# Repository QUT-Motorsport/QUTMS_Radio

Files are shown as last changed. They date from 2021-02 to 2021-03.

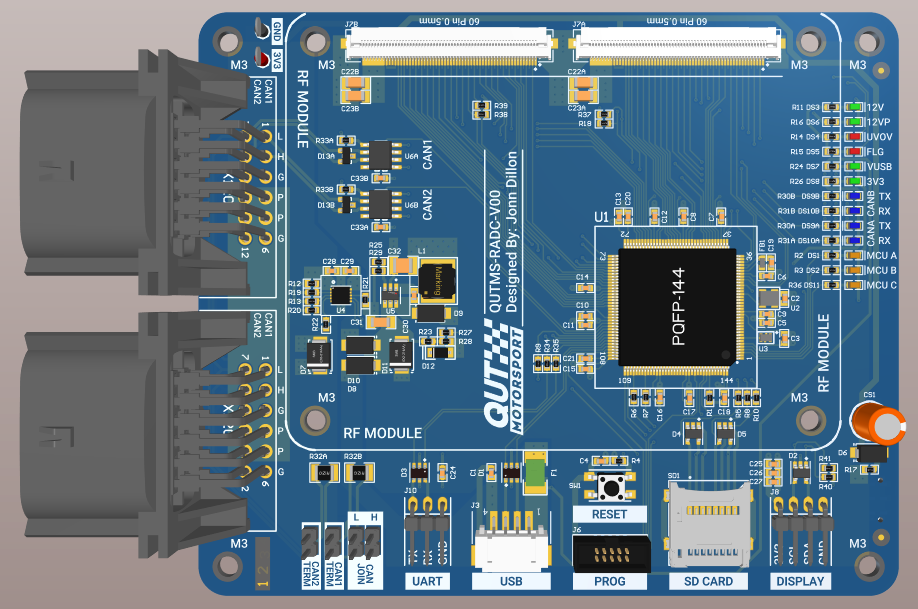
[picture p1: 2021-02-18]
RelatedImages/presentationAssembly_compute.PNG

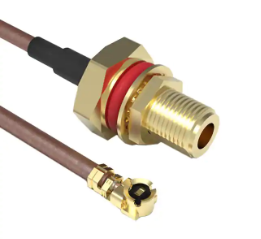
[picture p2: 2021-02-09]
RelatedImages/smaCableAssembly.PNG

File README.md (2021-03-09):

# QUTMS_Radio

## Purpose

The intent of this project is to create a robust communications link between the pits base station and one/many roving cars. Additionally the system is to provide extremely accurate RTK data.

## Project Structure

 - QUTMS-RADIO-MASTER-V00 | Overarching container for all of the projects. Open this and all other projects will open in Altium, also contains the larger mechanical assembly
 - QUTMS-RADIO-COMPUTE-V00 | The baseboard that will serve as the interface between any developed RF module and the car / base station systems
 - QUTMS-RADIO-GPS-V00 | GNSS Module
 - QUTMS-RADIO-M2M-V00 | Machine to Machine Radio module
 - QUTMS-RADIO-USB-V00 | Simple USB board to handle the issue of mounting a USB-C connector to a case
 - QUTMS-RADIO-COMPILE-V00 | Simple project to compile together all of the PCB''s into one panel
 - QUTMS-RADIO-CELL-V00 | An eventual board that will have cellular capabilities

## System configuration

For a full system there will be a total of 4 modules, 8 PCBs in total. For both the car side and pits side there will need to be a radio communications module, and a gnss module.

Ideally at the pits there will be one or two erectable tripods. One will have to hold the GNSS antenna, and needs to be high enough 

## Ordering Instructions

Only a single PCB has to be ordered for the system. This is the RAD-COMPILE pcb, a large PCB pane, 190x220mm, that contains all the PCBs needed for one side of the system (2x COMPUTE, 1x GNSS, 1x M2M).

On PCBWay's website, these are the setting required to correctly order the PCB. DO NOT DEVIATE OR RF WILL FAIL!

PCB Specification Section

- Board Type: Panel By Customer
- X-out Allowance: (Your choice, Accepting will allow some of the PCBs per panel to fail, so those failed panels will have to be accounted for in the total quantity. Not Accepting this will mean they will make a few extra PCB's (+$30) to ensure that you will have the quantity you specify of fully working panels) No/Yes 
- Different Design in Panel: 3
- Size: (Should auto fill on PCB upload) 220 x 190mm
- Quantity: 5-10 (X-Out = True -> 5, X-Out = False -> 10) (You need 2 panels min for a full system)
- Layers: 4
- Material: FR-4
- FR4-TG: TG150-160
- Thickness: 1.6mm
- Min Track/Spacing: 6/6mil
- Min Hole Size: 0.3mm
- Solder Mask: (Would prefer Green TBH due to solder mask dam thickness, but can be any colour (JUST NOT BLACK!)) Green / Purple / Blue
- Silkscreen: White
- Edge Connector: No
- Surface Finish: (Gold is an absolute must for RF) Immersion Gold (ENIG)
- Via Process: Tenting Vias
- Finished Copper: 1oz Cu
- Inner Copper: 1oz
- Extra PCB product number: (Your Choice)
- Additional Options: N/A

SMD-Stencil

- Stencil Type: Non-Framework
- Multi-level / Step Stencil: No
- Size (mm): 370x470mm (Valid Area 190 x 290mm)
- Stencil Side: Top
- Quantity: 1
- Thickness: 0.12mm
- Existing Fiducials: None (Accounted for in PCB design)
- Electropolishing: No
- Special Request: N/A

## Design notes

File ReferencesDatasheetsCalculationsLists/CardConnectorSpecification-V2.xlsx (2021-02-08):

PINOUT
ID | PWR | SIG | SIG DESC | STATE
1 | GND
2 |  | USART | TX | HIGH SPEED
3 | GND
4 |  | USART | RX | HIGH SPEED
5 | GND
6 |  | USART | CTS | HIGH SPEED
7 | GND
8 |  | USART | RTS | HIGH SPEED
9 | GND
10 |  | UART | TX | HIGH SPEED
11 | GND
12 |  | UART | RX | HIGH SPEED
13 | GND
14 |  | SPI | CLK | HIGH SPEED
15 | GND
16 |  | SPI | MISO | HIGH SPEED
17 | GND
18 |  | SPI | MOSI | HIGH SPEED
19 | GND
20 |  | SPI | CS | HIGH SPEED
21 | GND
22 |  | I2C | CLK | HIGH SPEED
23 | GND
24 |  | I2C | SDA | HIGH SPEED
25 | GND
26 |  | GENERIC |  | UNKNOWN
27 | GND
28 |  | GENERIC |  | UNKNOWN
29 | GND
30 |  | GENERIC |  | UNKNOWN
31 | GND
32 |  | GENERIC |  | UNKNOWN
33 | GND
34 |  | GENERIC |  | UNKNOWN
35 | GND
36 |  | GENERIC |  | UNKNOWN
37 | GND
38 |  | GENERIC |  | UNKNOWN
39 | GND
40 |  | GENERIC |  | UNKNOWN
41 | GND
42 |  | GENERIC |  | UNKNOWN
43 | GND
44 |  | GENERIC |  | UNKNOWN
45 | GND
46 |  | MODULE DET |  | STATIC
47 |  | MODULE DET |  | STATIC
48 | GND
49 | RTC BAT |  |  | RTC
50 | RTC BAT |  |  | RTC
51 | GND
52 | 3V3 |  |  | PWR
53 | 3V3 |  |  | PWR
54 | 3V3 |  |  | PWR
55 | 3V3 |  |  | PWR
56 | 3V3 |  |  | PWR
57 | 3V3 |  |  | PWR
58 | 3V3 |  |  | PWR
59 | 3V3 |  |  | PWR
60 | 3V3 |  |  | PWR

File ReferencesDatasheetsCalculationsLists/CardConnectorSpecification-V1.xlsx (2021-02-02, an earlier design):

RADC / RADM / RADG Card Interconnect specification
PCI-E Right Angle Connector: PCIE-036-02-F-D-RA
Bottom Row |  | Top Row |  | Each Card Requires
Pin | Intent | Pin | Intent
 |  |  |  | 1 SPI | 4
A1 | GND | B1 | 3V3 | 1 Syn USART | 5
A2 | SPI MISO | B2 | RTC BAT | 1 Asyn UART | 2
A3 | SPI MOSI | B3 | I2C SDA | 1 I2C | 2
A4 | SPI CLK | B4 | I2C SCL | 8 Extra | 8
A5 | SPI CS | B5 | 3V3 | Module Det | 1 | ADC Voltage
A6 | GND | B6 | USART1 TX
A7 | UART2 TX | B7 | USART1 RX
A8 | UART2 RX | B8 | USART1 RTS
A9 | Module Detect | B9 | USART1 CTS
A10 | Module Detect | B10 | USART1 DTR
A11 | GND | B11 | 3V3 |  |  |  | Module 1 | 26
 |  |  |  |  |  |  | Module 2 | 26
A12 | GND | B12 | 3V3 |  |  |  | SD | 7
A13 | Connected Pin | B13 | Connected Pin |  |  |  | CAN | 3
A14 | Connected Pin | B14 | Connected Pin |  |  |  | PWR | 3
A15 | Connected Pin | B15 | Connected Pin |  |  |  | I2C | 2
A16 | Connected Pin | B16 | Connected Pin
A17 | Connected Pin | B17 | Connected Pin
A18 | GND | B18 | 3V3

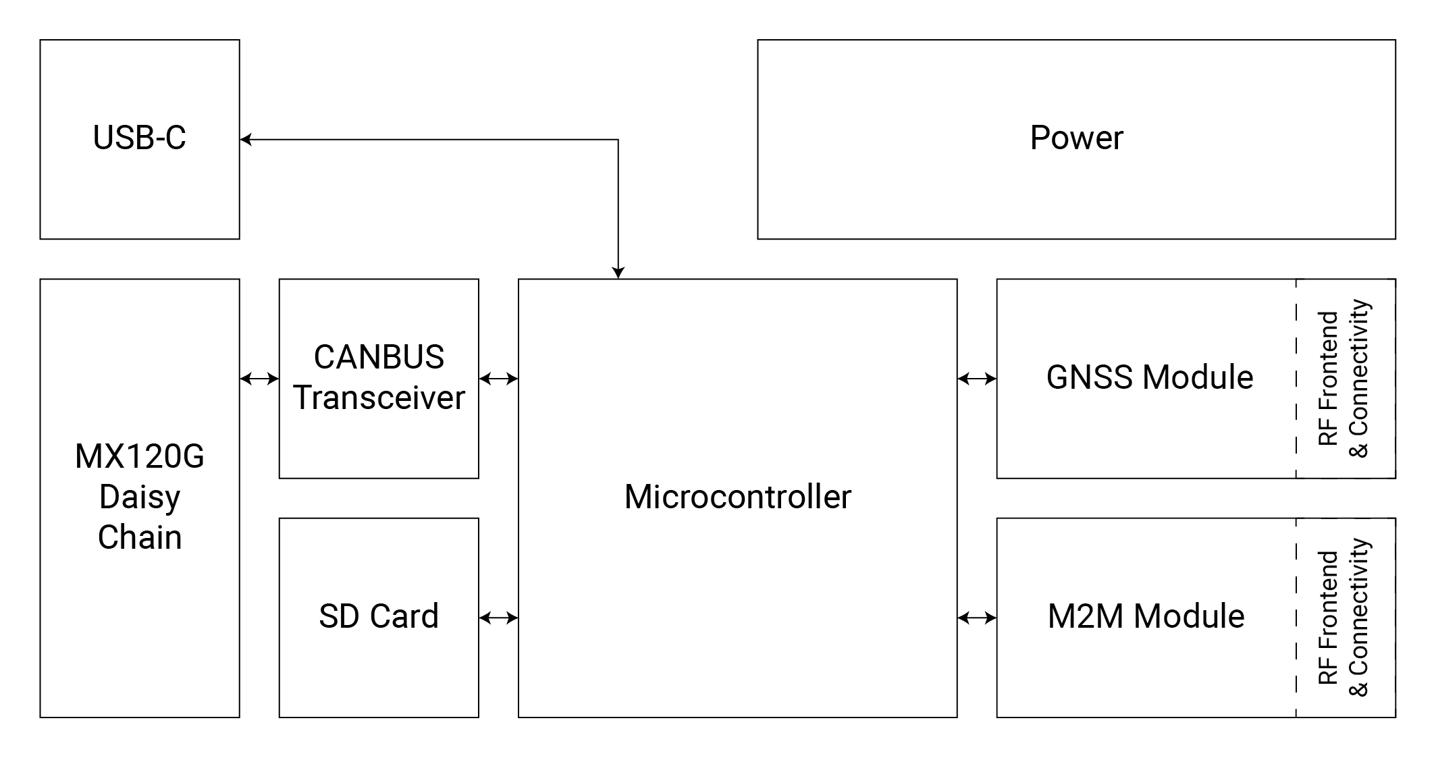
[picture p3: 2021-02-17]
RelatedImages/requirementsArchitectureDiagram-01.png

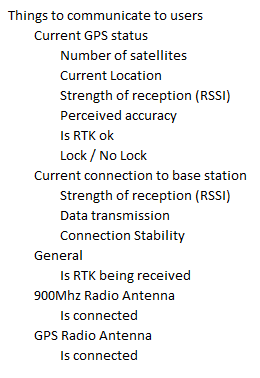
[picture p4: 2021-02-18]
RelatedImages/oledDisplayRequirements.PNG

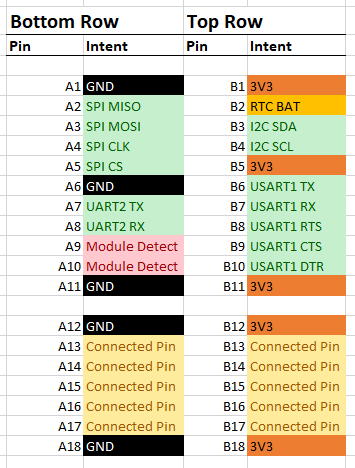
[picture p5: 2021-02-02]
RelatedImages/cardConnectorSpecification-V1.PNG

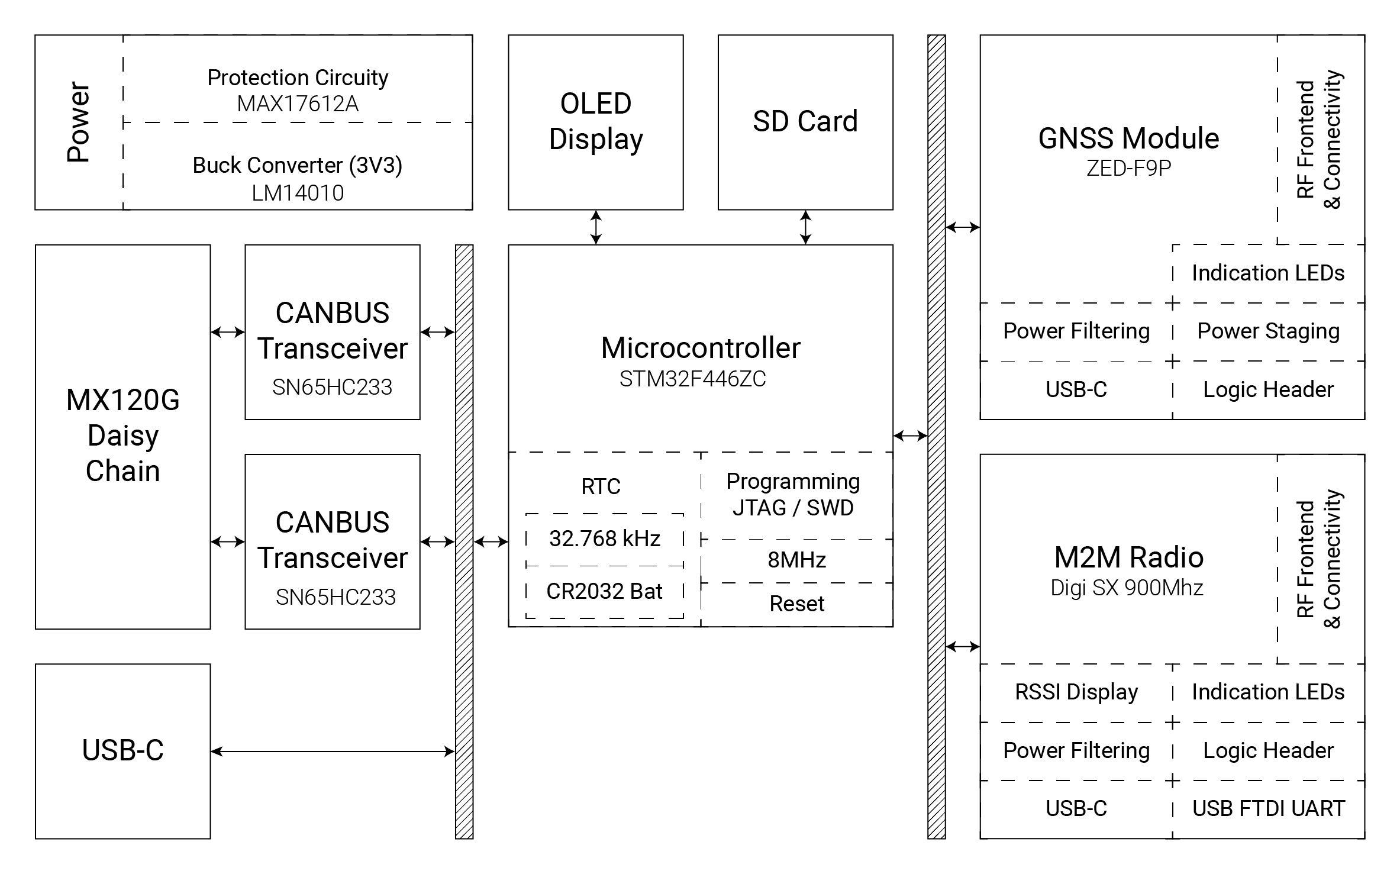
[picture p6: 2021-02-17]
RelatedImages/ultimateArchitectureDiagram-01.png

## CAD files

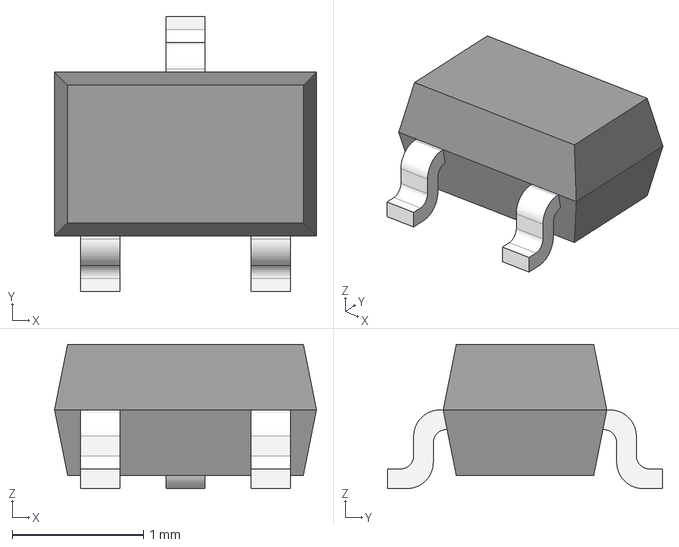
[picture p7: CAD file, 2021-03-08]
3DModels/SC70-3.step
2.00 x 2.10 x 1.10 mm

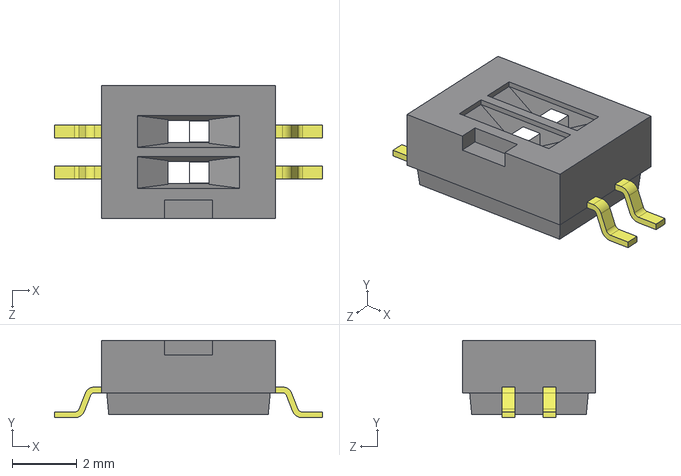
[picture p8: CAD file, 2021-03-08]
3DModels/CUI_DEVICES_DS05-127-2-02BK-SMT-TR.step
8.30 x 2.40 x 4.11 mm

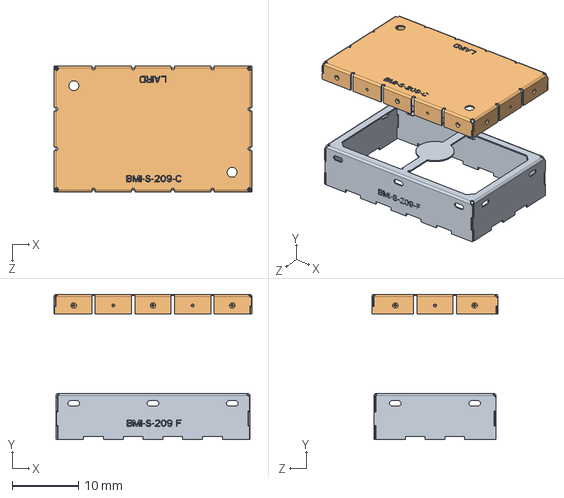
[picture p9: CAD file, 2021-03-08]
3DModels/Laird-BMI-S-209 Frame and Cover.STEP
30.0 x 22.0 x 19.1 mm
Laird-BMI-S-209-F and BMI-S-209-C_BMI-S-209-F
Laird-BMI-S-209-F and BMI-S-209-C_BMI-S-209-C

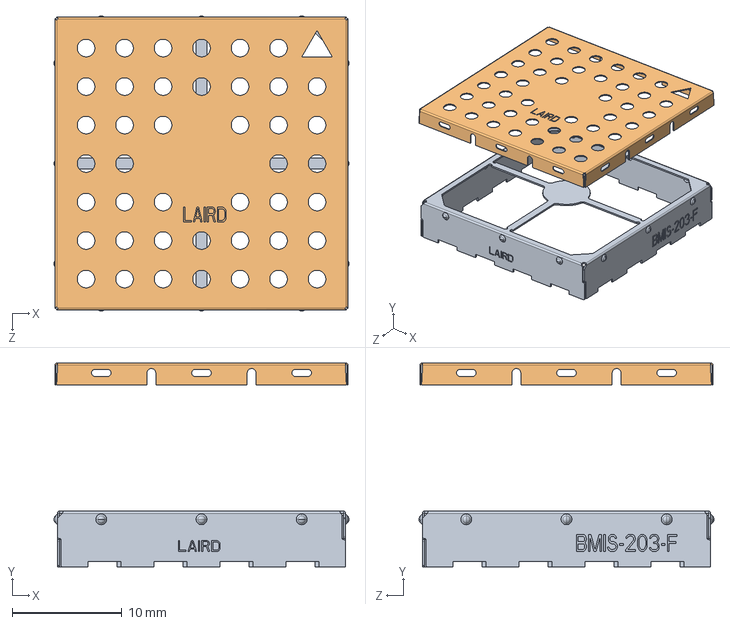
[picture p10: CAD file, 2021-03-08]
3DModels/Laird-BMI-S-203 Frame and Cover.STEP
26.8 x 18.5 x 26.8 mm
Laird-BMI-S-203-F and BMI-S-203-C_BMI-S-203-F
Laird-BMI-S-203-F and BMI-S-203-C_BMI-S-203-C

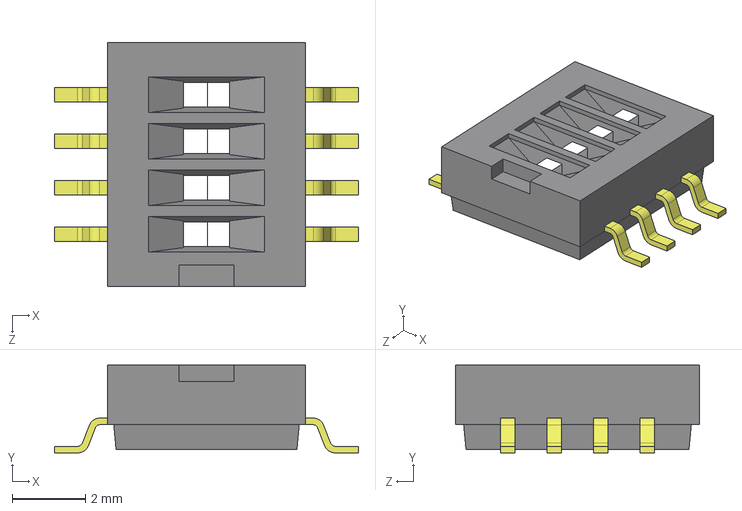
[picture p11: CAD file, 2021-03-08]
3DModels/CUI_DEVICES_DS05-127-2-04BK-SMT-TR.step
8.30 x 2.40 x 6.65 mm

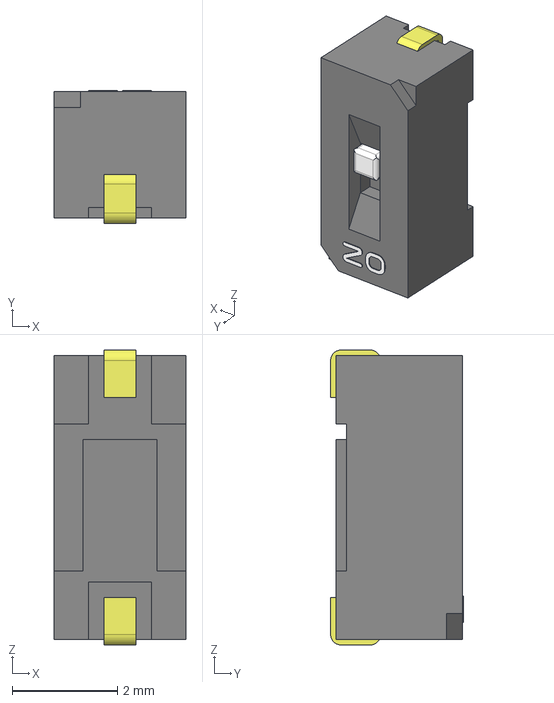
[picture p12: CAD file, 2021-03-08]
3DModels/CHS-01TA.stp
2.50 x 2.52 x 5.60 mm
_CHS-01-J-body
_CHS-slider

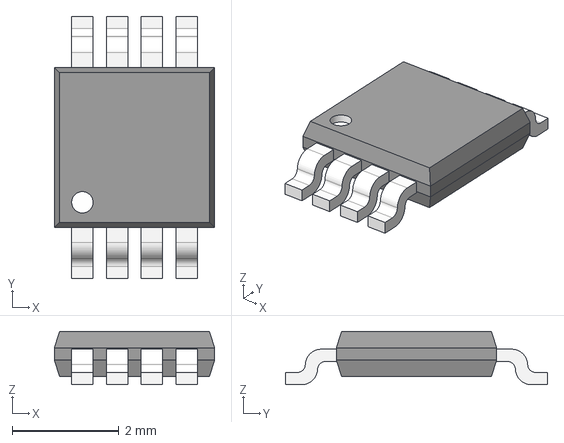
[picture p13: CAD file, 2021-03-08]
3DModels/MSOP-08 0.65p 3mm.step
3.00 x 4.90 x 1.00 mm

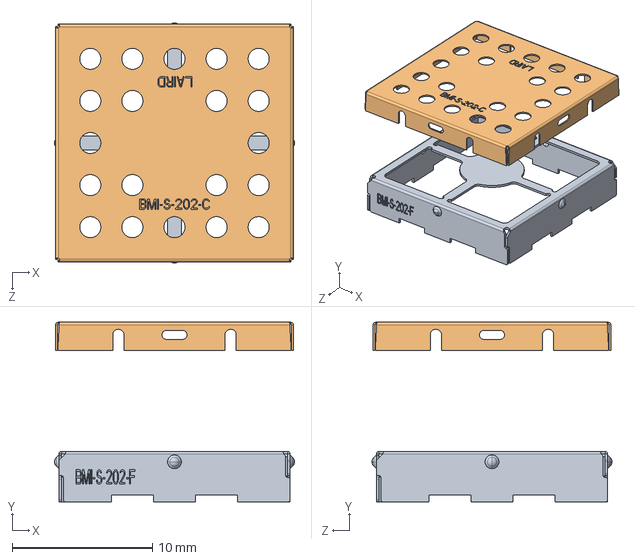
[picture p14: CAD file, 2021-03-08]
3DModels/Laird-BMI-S-202 Frame and Cover.STEP
17.1 x 12.8 x 17.1 mm
Laird-BMI-S-202-F and BMI-S-202-C_BMI-S-202-F
Laird-BMI-S-202-F and BMI-S-202-C_BMI-S-202-C

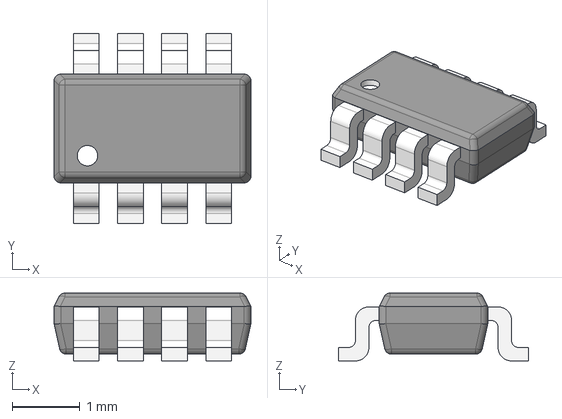
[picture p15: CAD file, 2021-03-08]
3DModels/TSOT-8.step
2.90 x 2.80 x 1.00 mm

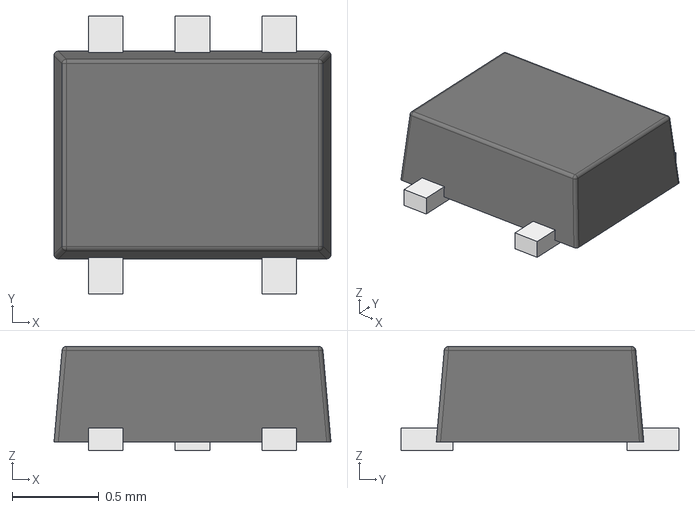
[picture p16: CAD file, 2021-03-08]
3DModels/SOT-23-5-TI-DRL v2.step
1.60 x 1.60 x 0.6 mm

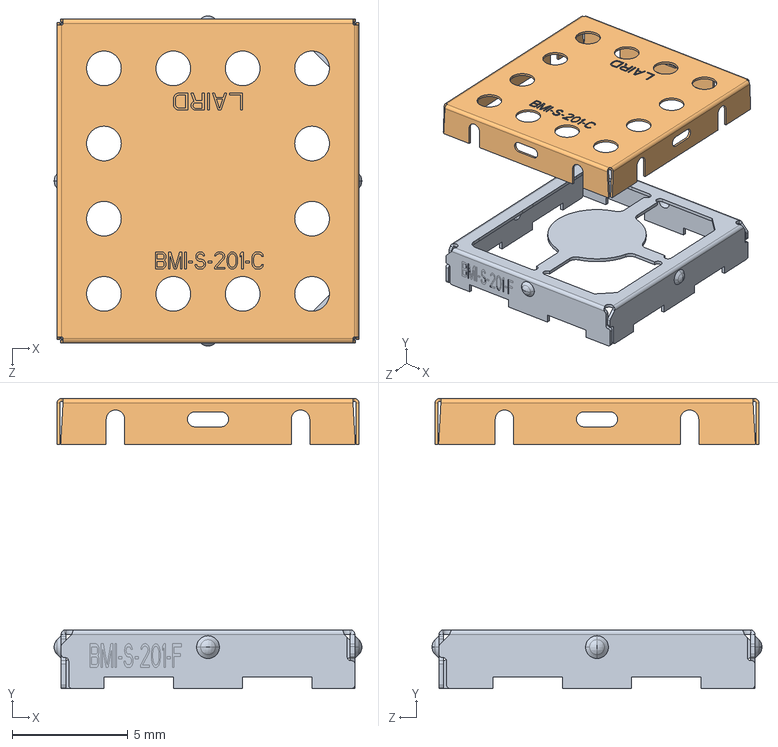
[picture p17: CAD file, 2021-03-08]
3DModels/Laird-BMI-S-201 Frame and Cover.STEP
13.3 x 12.5 x 14.3 mm
Laird-BMI-S-201-F and BMI-S-201-C_BMI-S-201-F
Laird-BMI-S-201-F and BMI-S-201-C_BMI-S-201-C

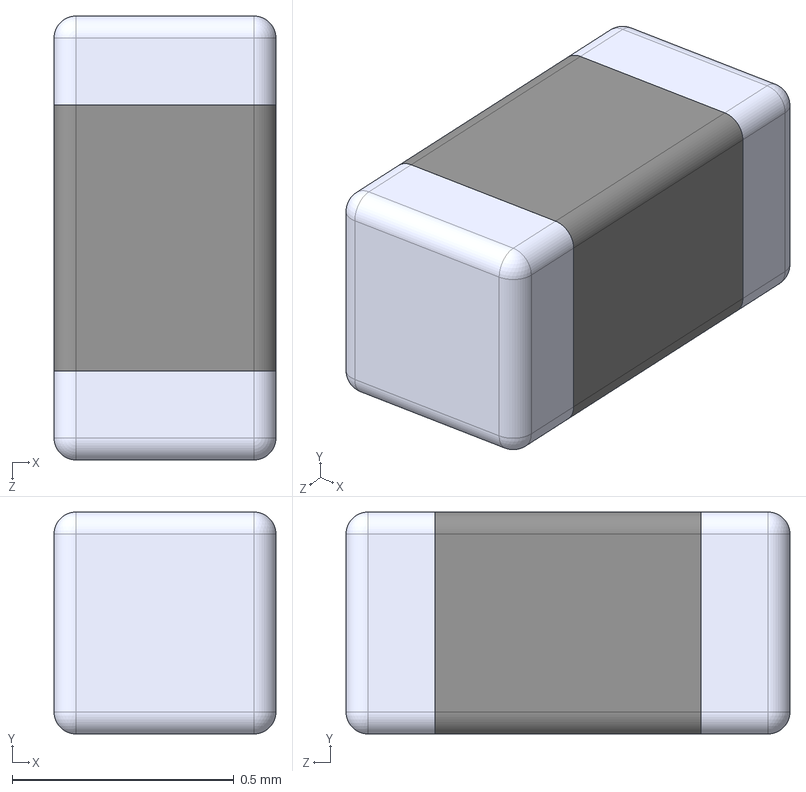
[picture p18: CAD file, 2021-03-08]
3DModels/ferrite_bead_0402.STEP
0.5 x 0.5 x 1.00 mm

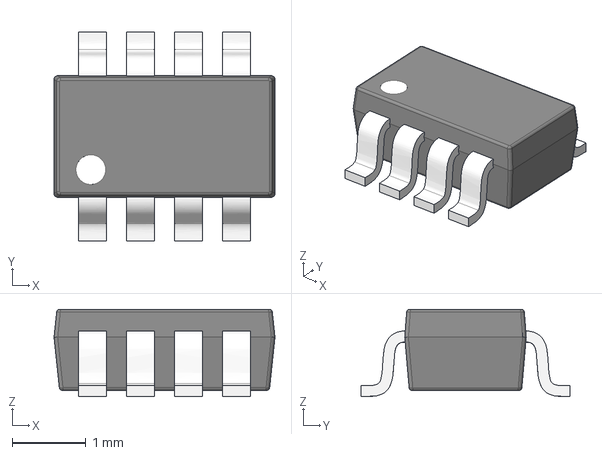
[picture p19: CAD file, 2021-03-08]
3DModels/SOT23-8.stp
3.00 x 2.84 x 1.18 mm

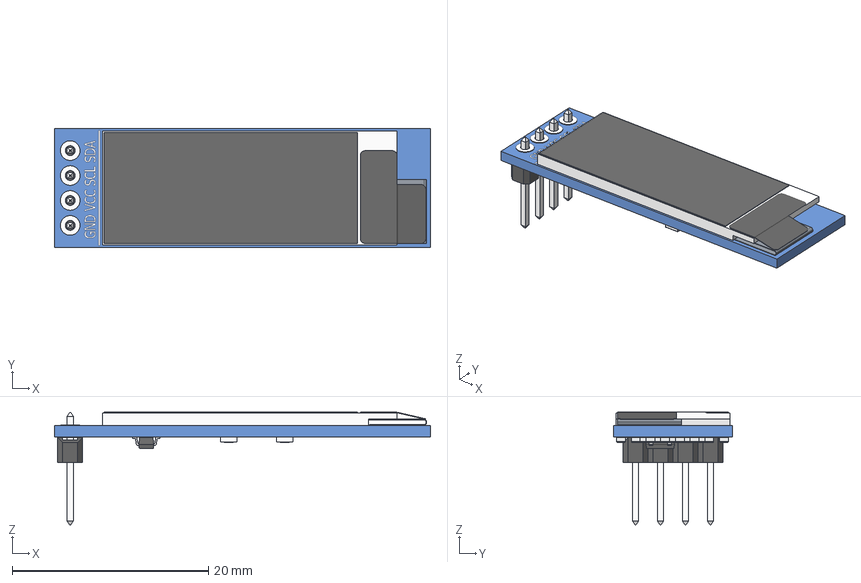
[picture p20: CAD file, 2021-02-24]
3DModels/OLED_0.91_128x32.stp
38.3 x 12.1 x 11.5 mm
OLED_0.91_128x32
Pin Header 4 x 1 TH 2.54mm Pitch
RESC-0603 x 13
2SD0601A

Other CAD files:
3DModels/OLEDDisplay1-3inch.stp
3DModels/1812_RES.stp
3DModels/TSSOP-14 0.65p 4.4mm.step
3DModels/pqfpfp144_p0-5_l20_w20.stp
3DModels/022288030.stp
3DModels/022288040.stp
3DModels/0ZCJ0005FF2E.step
3DModels/20-Pin Shrouded Header (IDC) Straight.stp
3DModels/30326-6002.stp
3DModels/61300411121_Download_STP_61300411121_rev1.stp
3DModels/68021-x08.igs
3DModels/74279270_Download_STP_WE-CBF-0402_rev1.stp
3DModels/Aluminum_electrolytic_capacitor_radial_D6.3_H9_PinD0.5_Pitch2.5_nominal_orange.step
3DModels/CUI_PJ-102A.STEP
3DModels/JS202011JAQN.stp
3DModels/JS202011JCQN.stp
3DModels/JST - PH - SMD (R) - 4Pin - 2.00mm.stp
3DModels/JST - PH - Thru (V) - 4Pin - 2.00mm.stp
3DModels/LQFP100_14X14X1.6_P0.5_ST.step
3DModels/M3x1.8mm Hex Nut.step
3DModels/M3x8.STEP
3DModels/NFE31PT101C1E9L.STEP
3DModels/PCIE-036-02-F-D-RA.stp
3DModels/SC-74-3.stp
3DModels/SC-74-4.stp
3DModels/SC-74-5.stp
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

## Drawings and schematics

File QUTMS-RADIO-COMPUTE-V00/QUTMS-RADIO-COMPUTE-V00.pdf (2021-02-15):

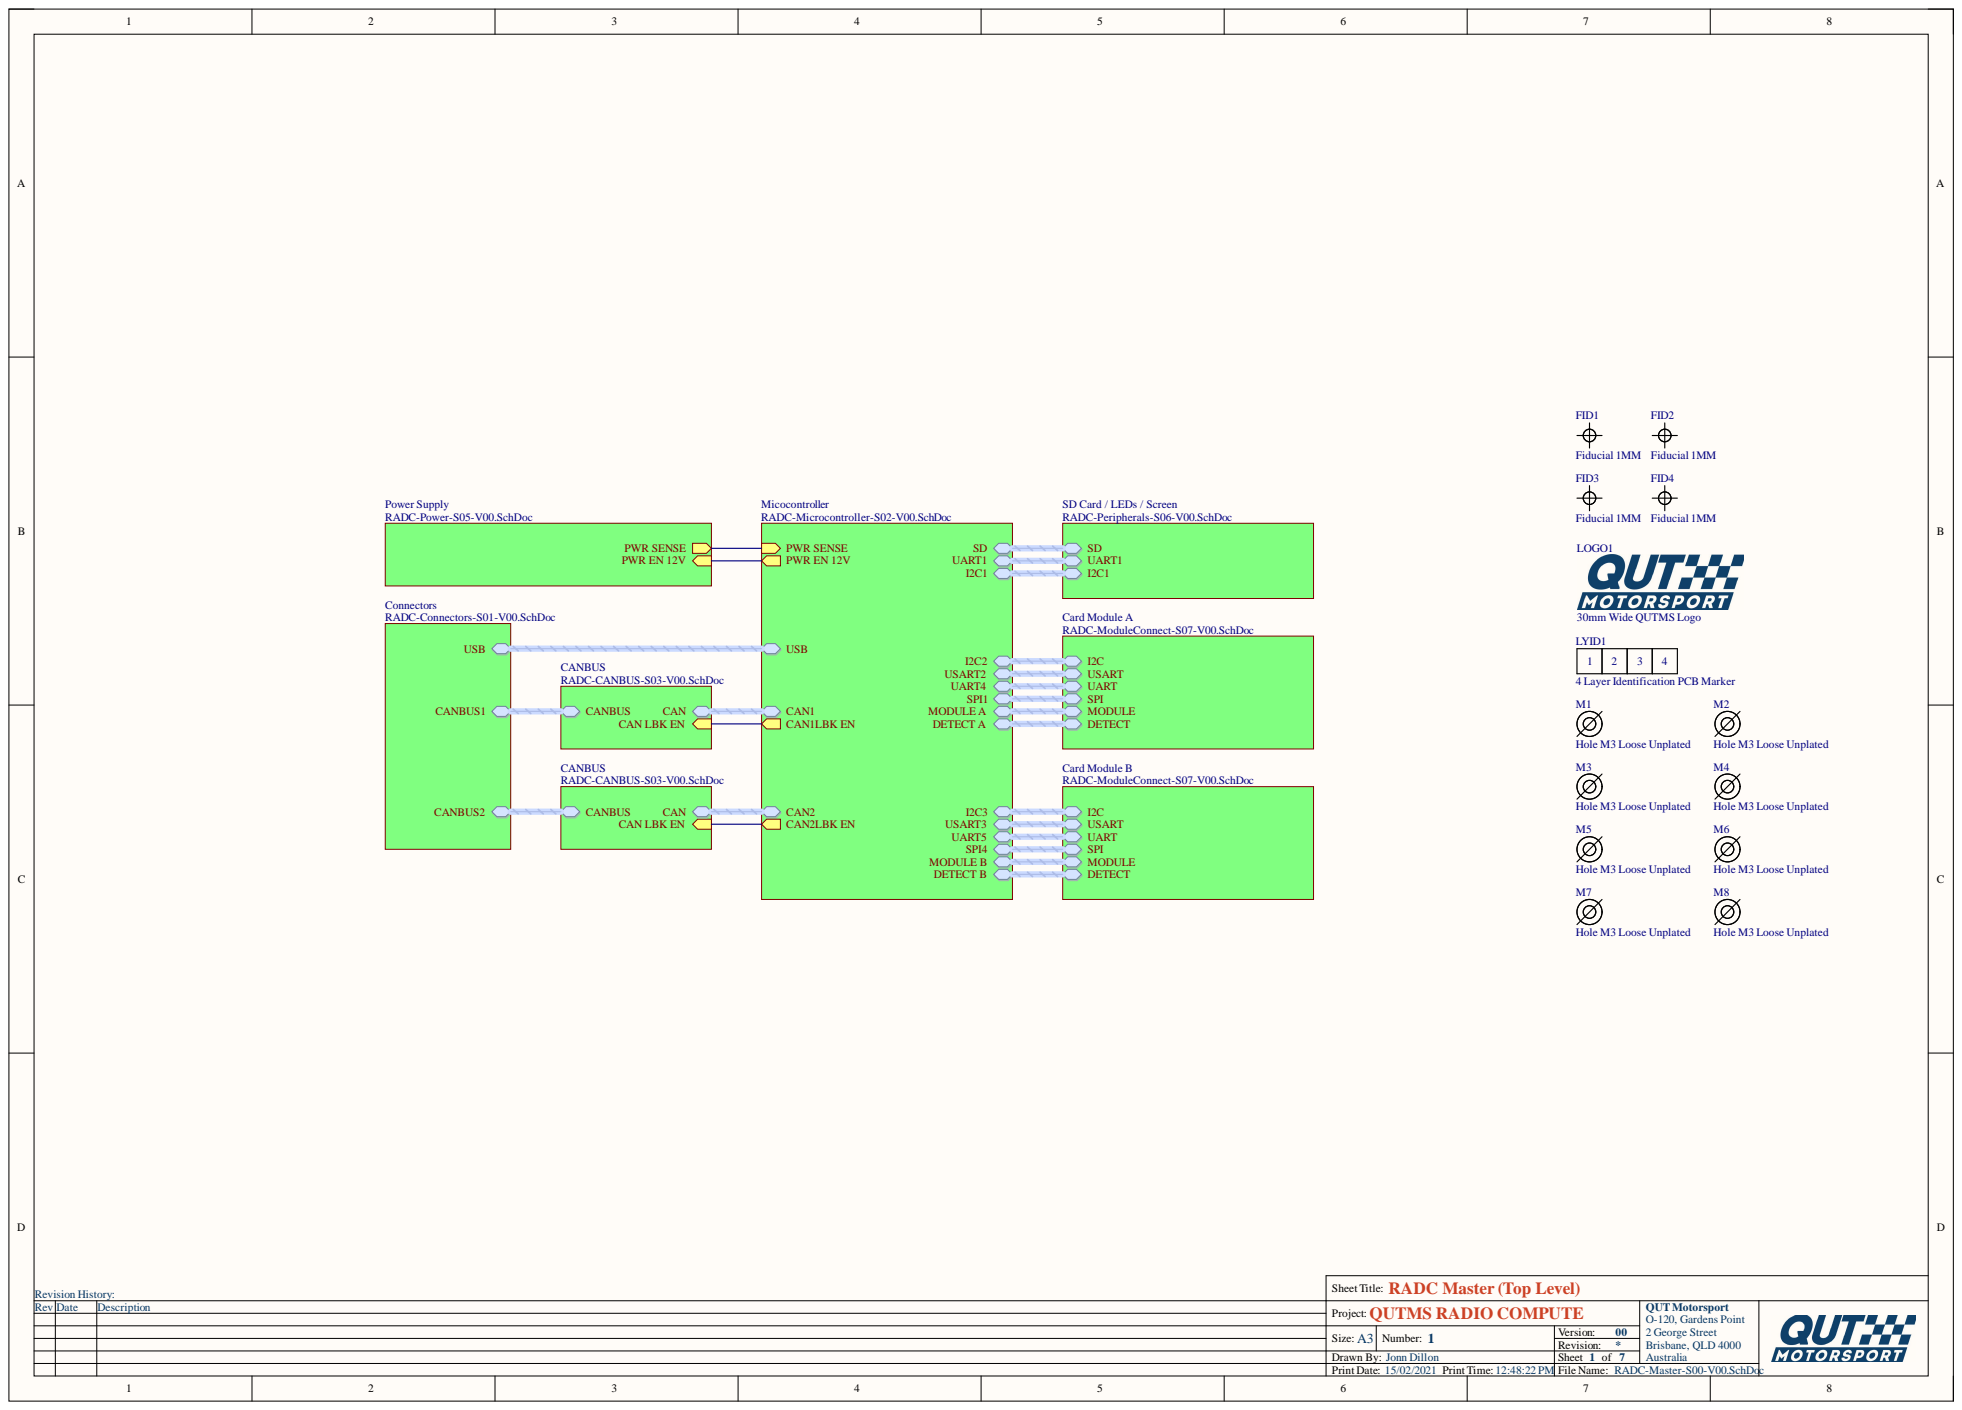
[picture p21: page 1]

SD Card / LEDs / Screen
RADC-Peripherals-S06-V00.SchDoc

4 Layer Identification PCB Marker

Sheet Title: RADC Master (Top Level)
QUTMS RADIO COMPUTE

Drawn By: Jonn Dillon

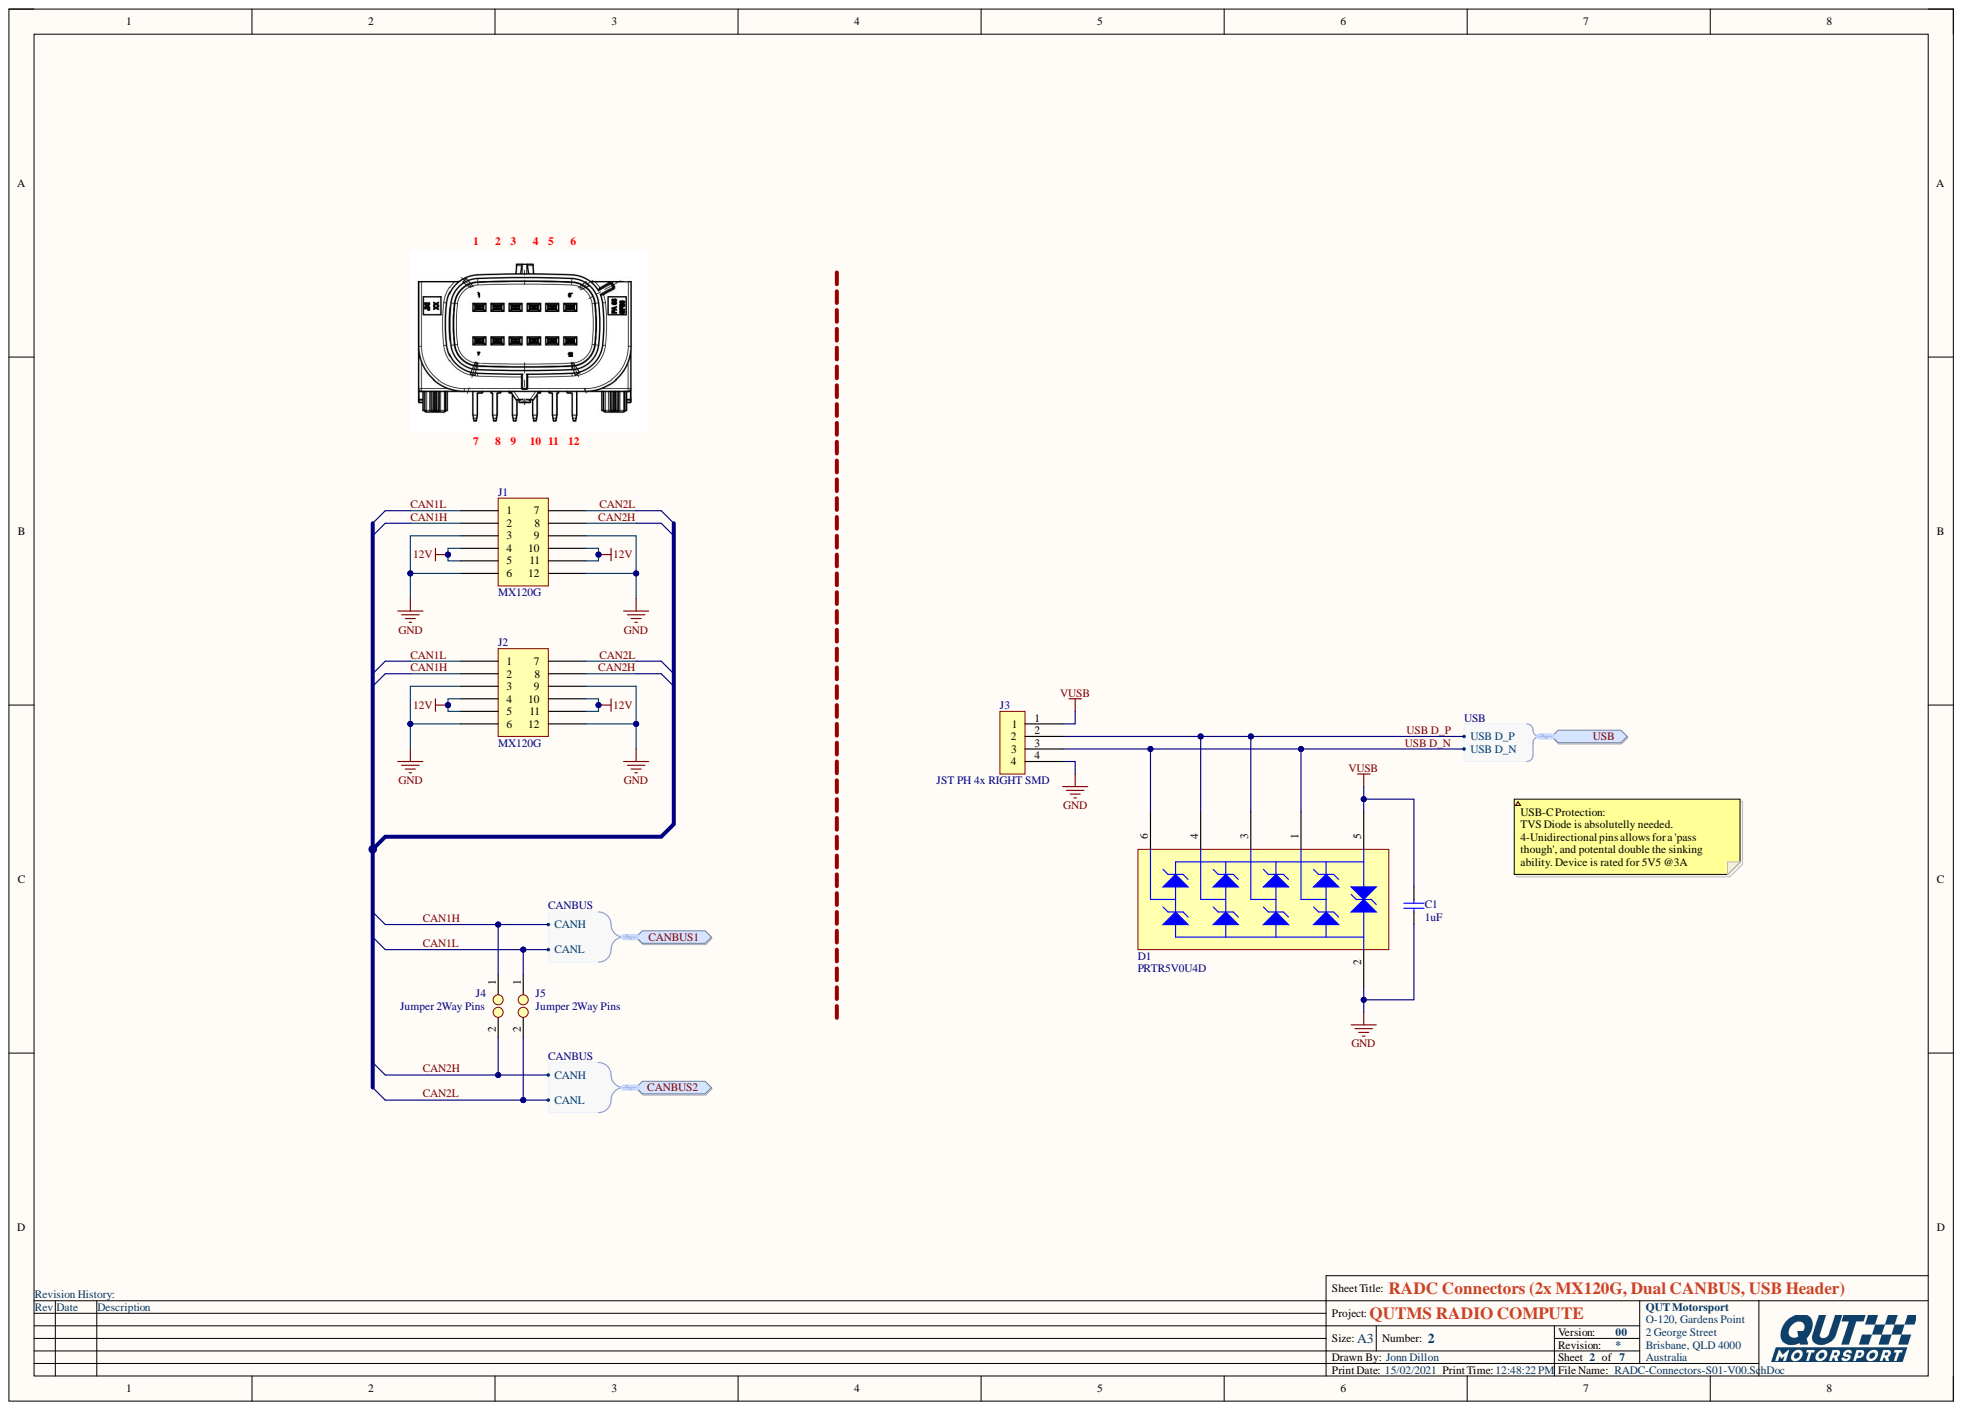
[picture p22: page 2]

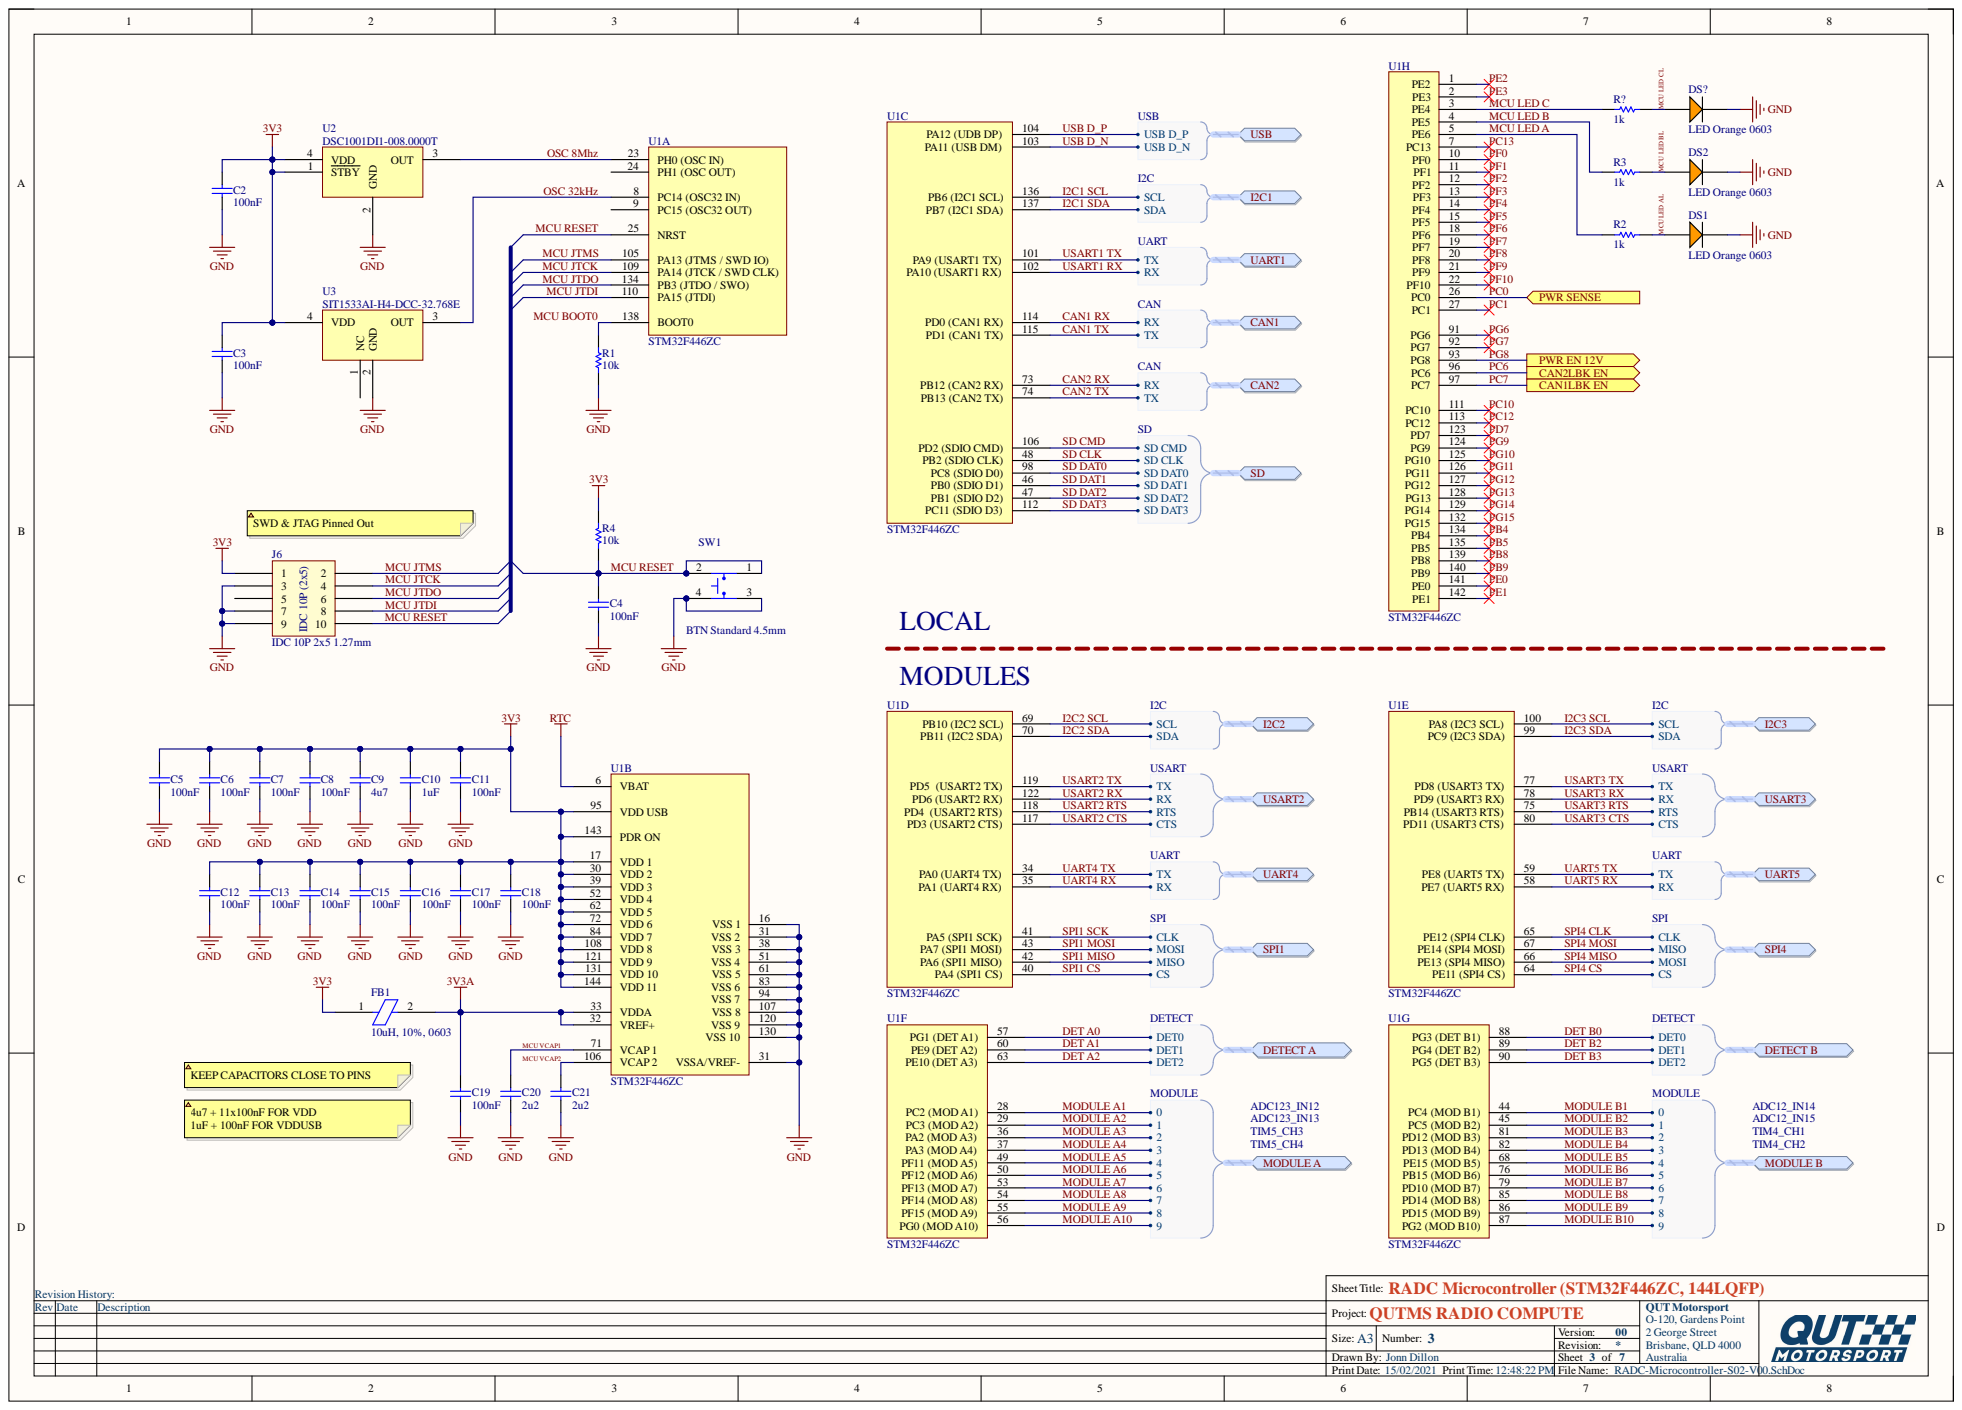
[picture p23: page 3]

USB D_P USB D_N USB
USB D_P USB D_N I2C1 SCL I2C1 SDA USART1 R

MCU LED AL MCU LED BL
DS2 LED O

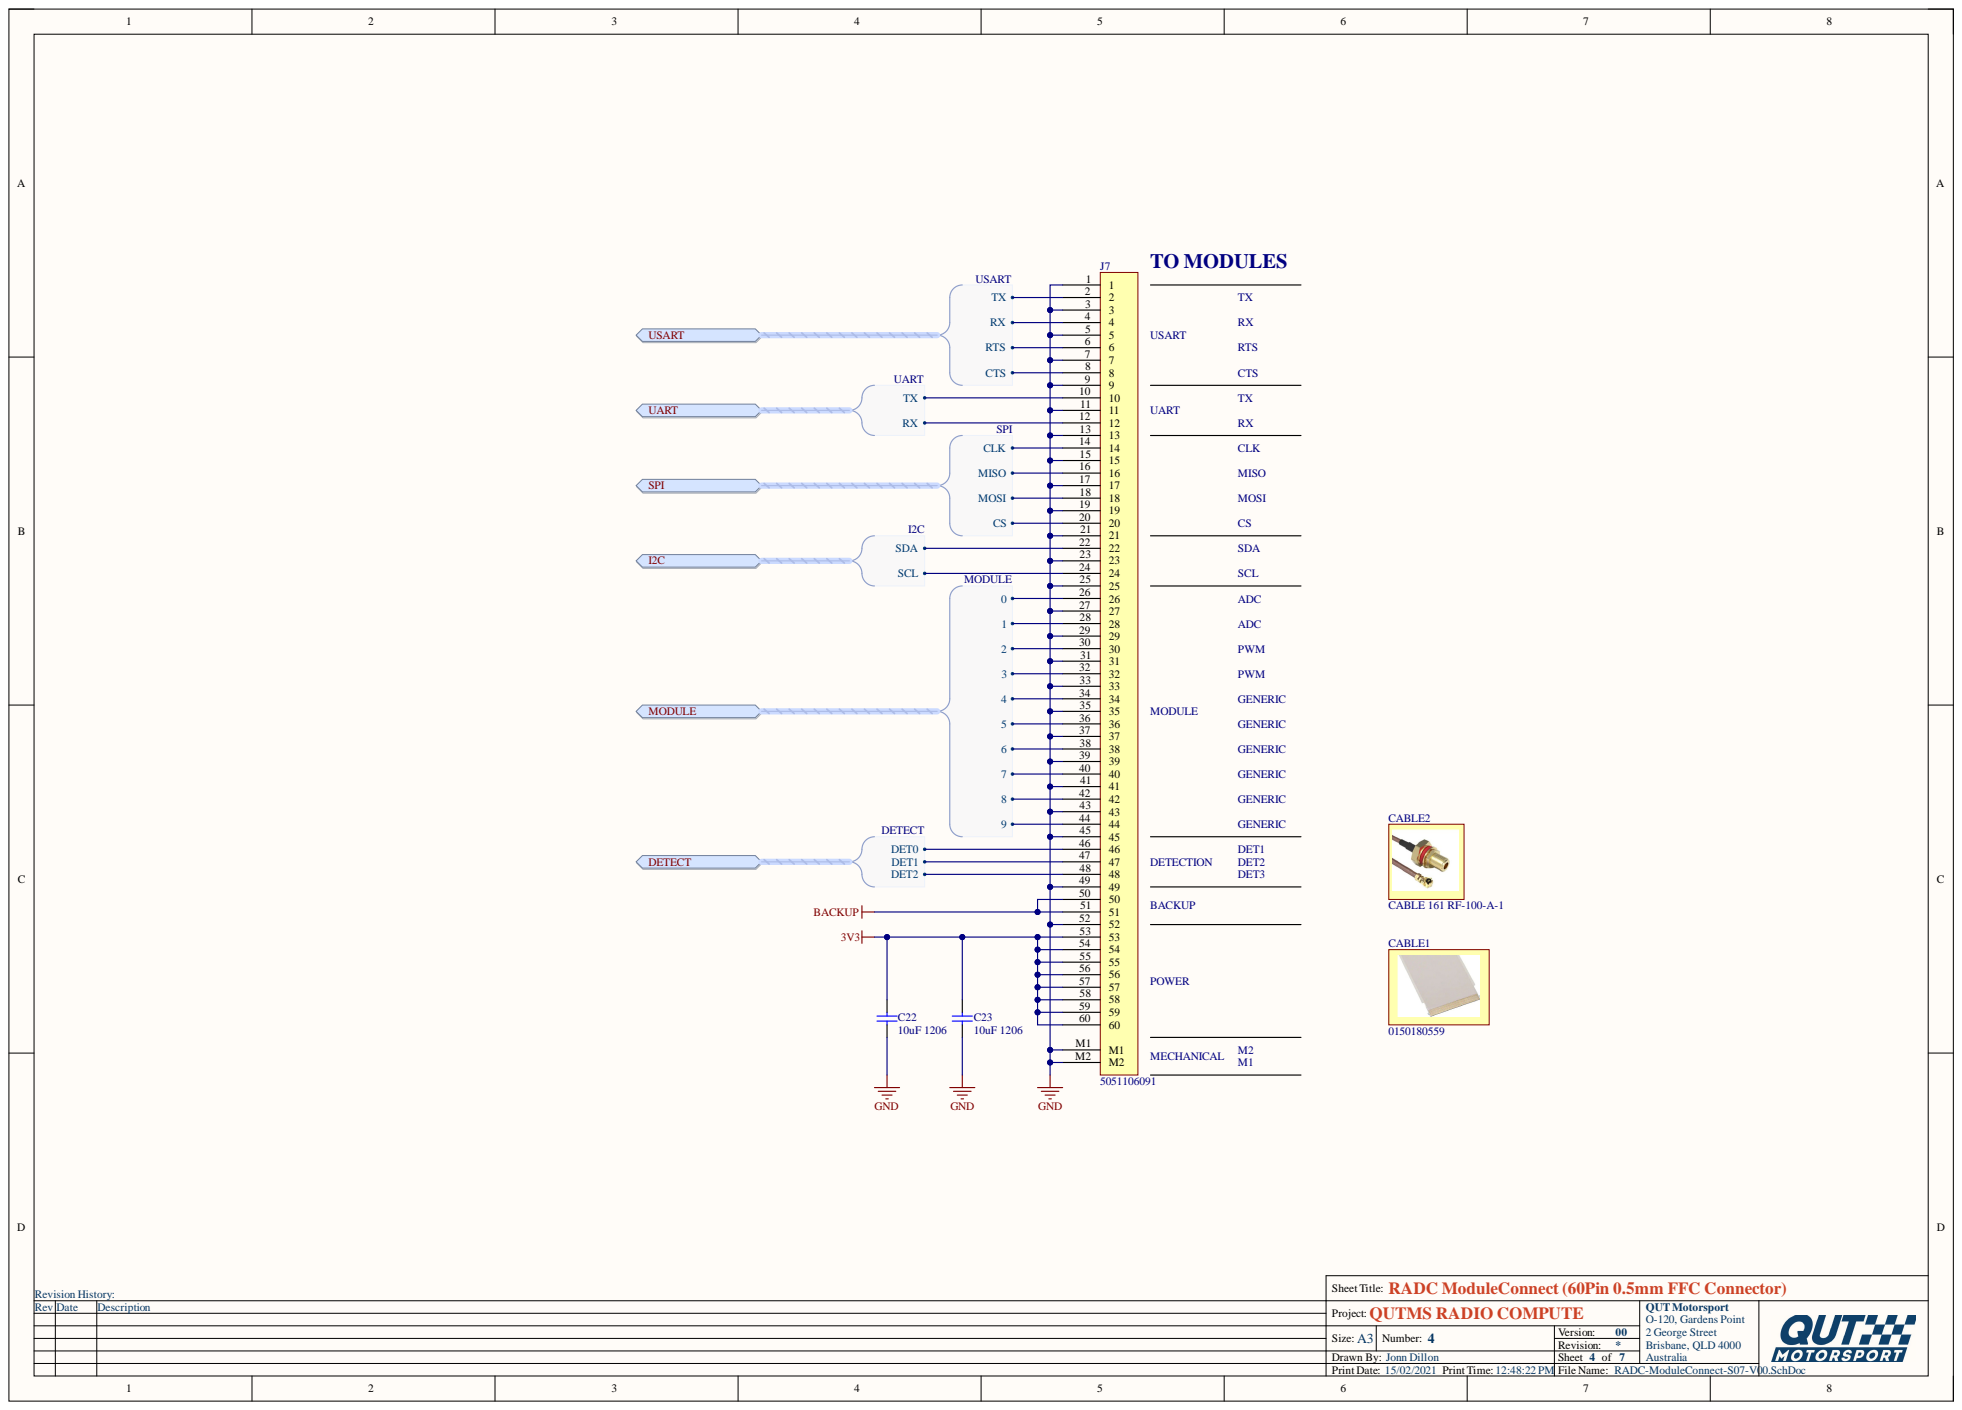
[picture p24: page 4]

50 50
51 51
52 52
53 53
54 54
55 55
56 56
57 57
58 58
59 59
60 60

M1 M1
M2 M2

Sheet Title: RADC ModuleConnect (60Pin 0.5mm FFC Connector)

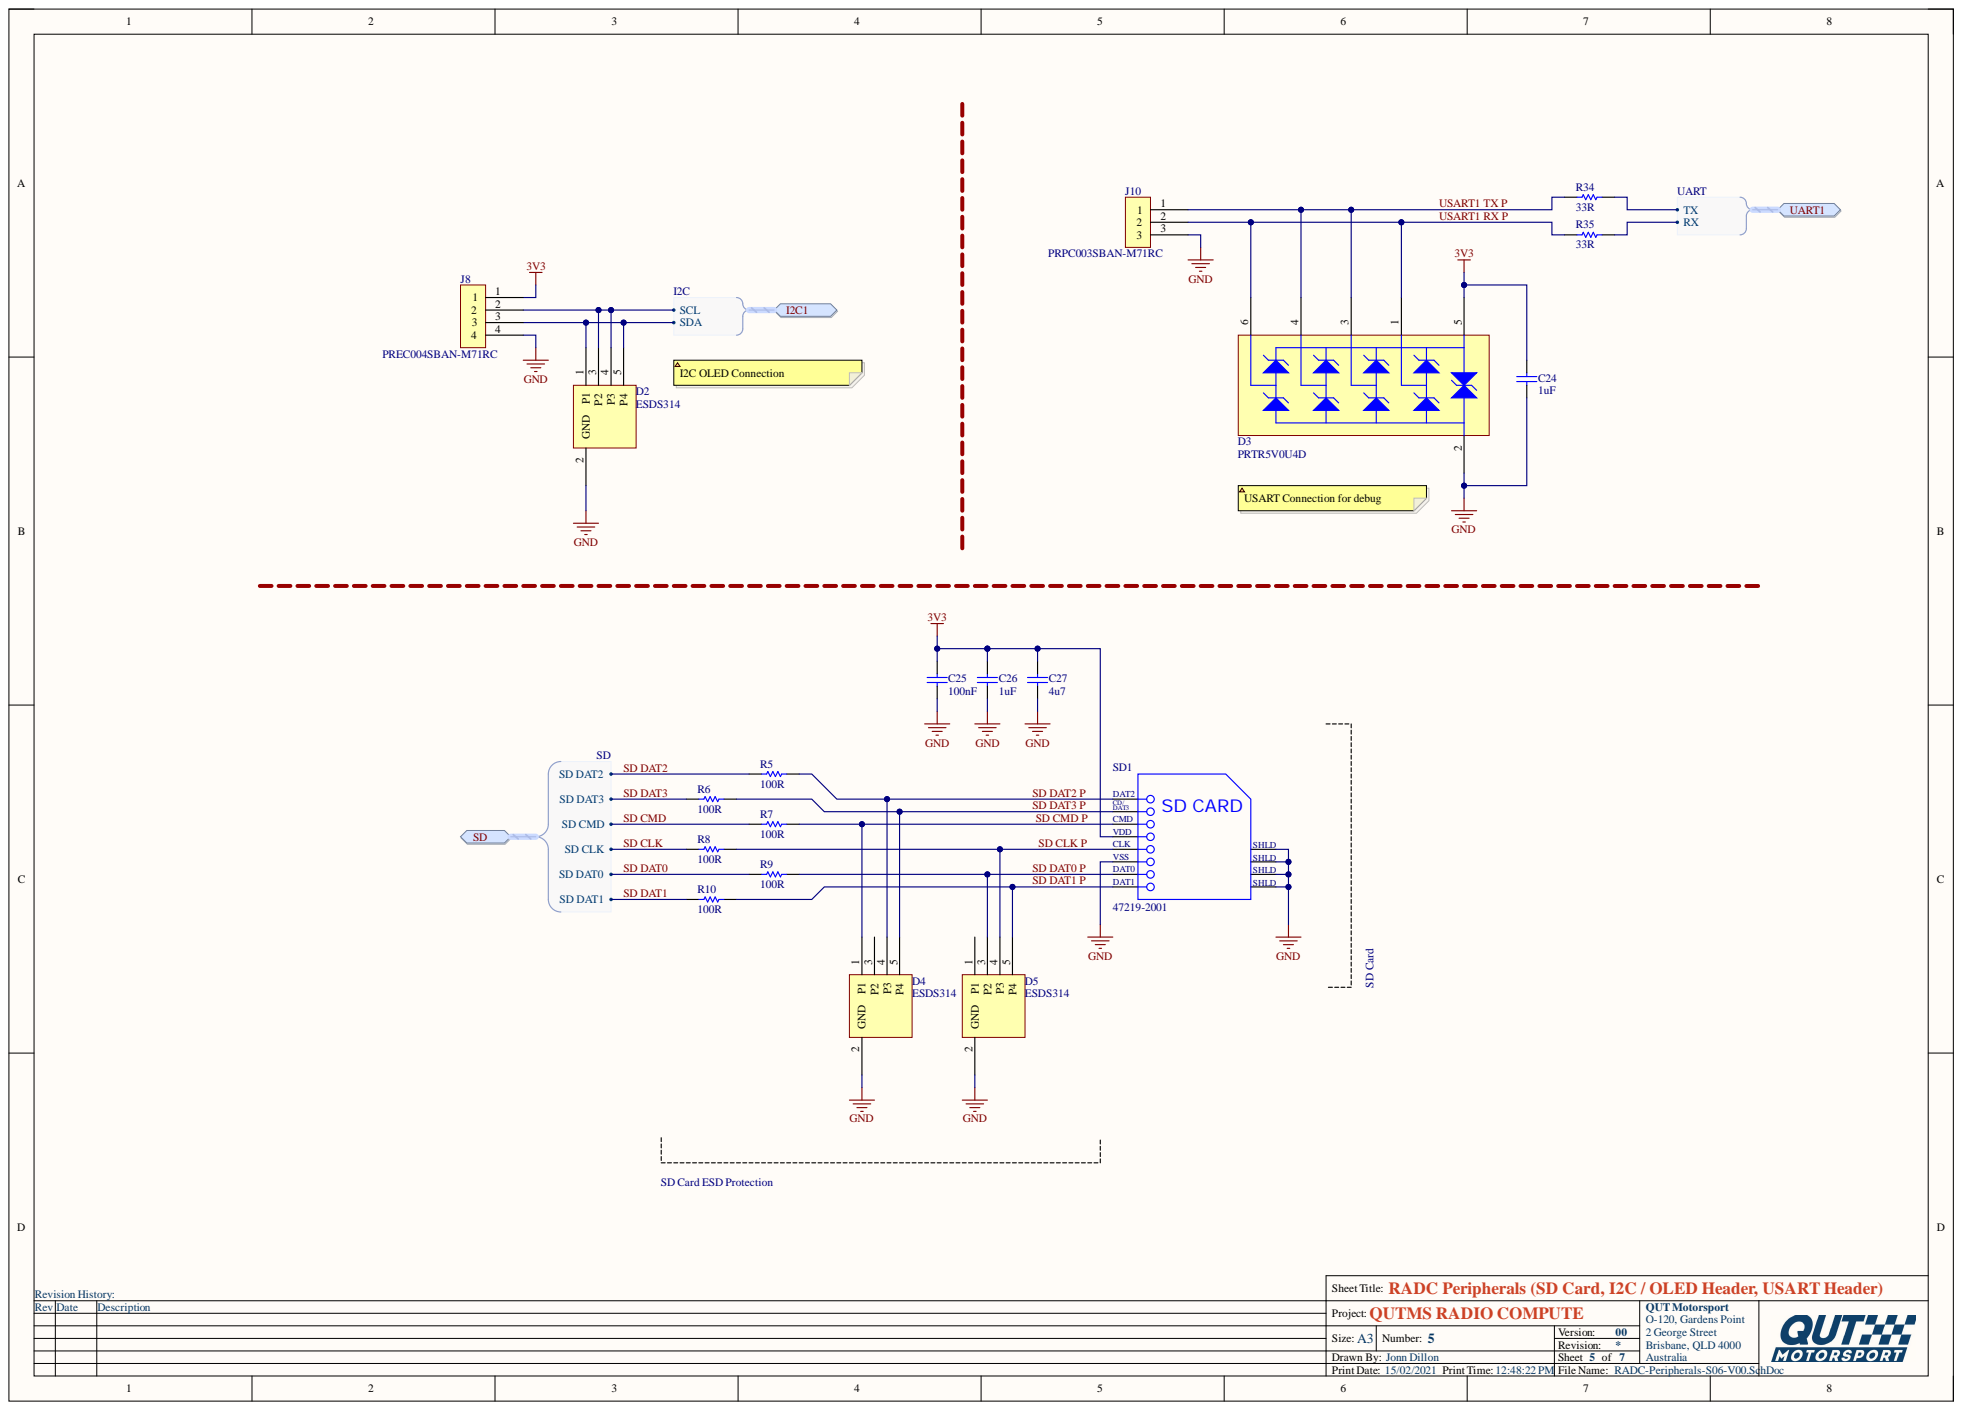
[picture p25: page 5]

USART Connection for debug

SD Card ESD Protection

Sheet Title: RADC Peripherals (SD Card, I2C / OLED Header, USART Header)

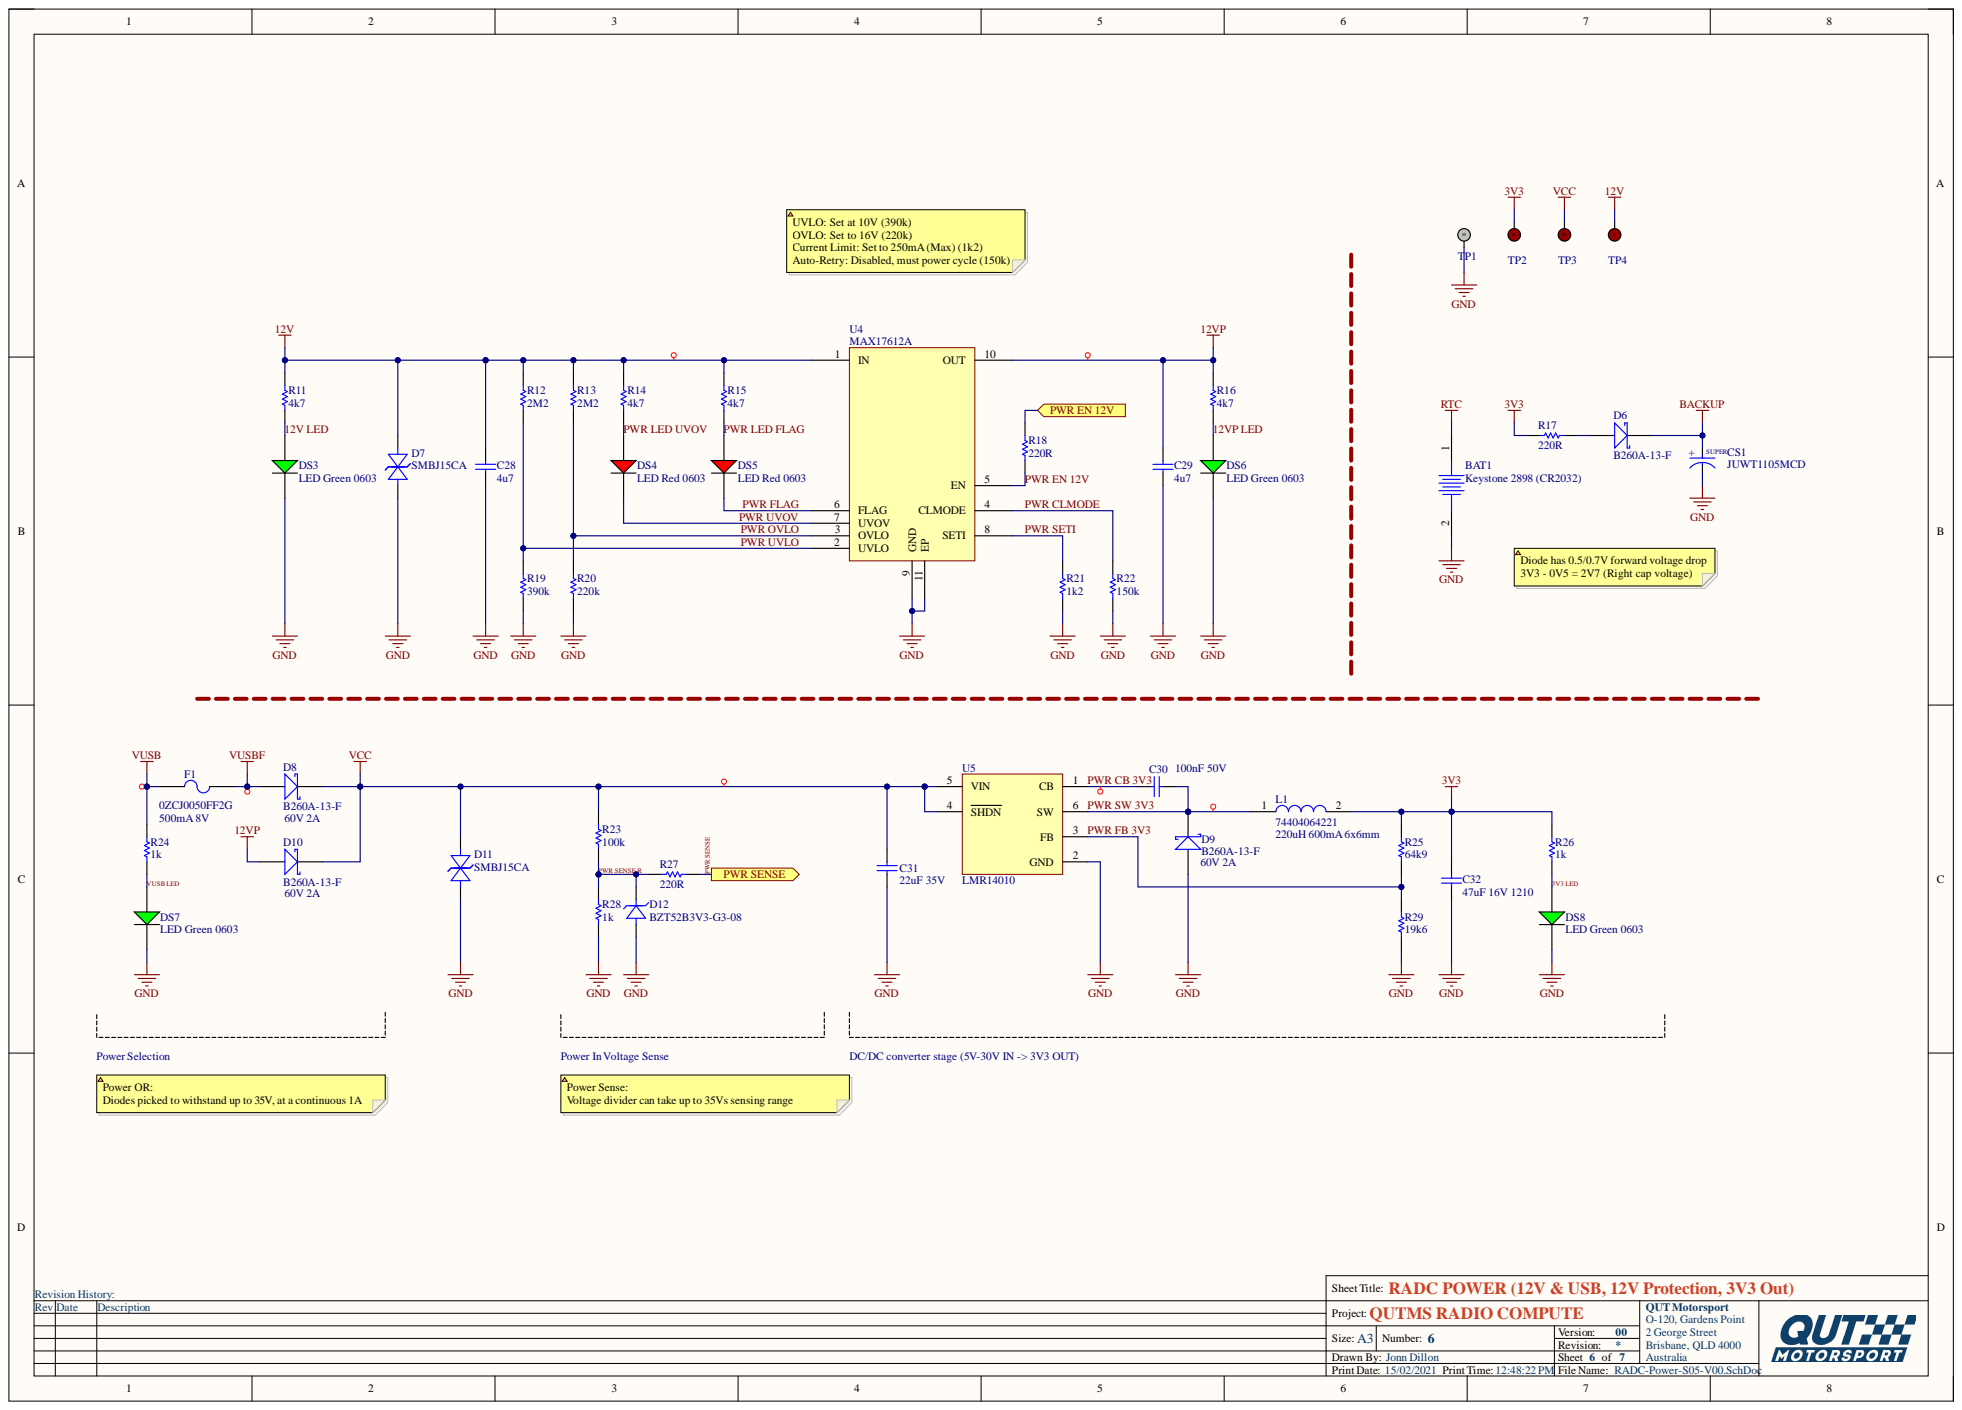
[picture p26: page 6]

UVLO: Set at 10V (390k)
OVLO: Set to 16V (220k)
Current Limit: Set to 250mA(Max) (1k2)
Auto-Retry: Disabled, must power cycle (150k)

Diode has 0.5/0.7V forward voltage drop
3V3 - 0V5 = 2V7 (Right cap voltage)

SHDN 4 | PWR FB 3V3

Power OR:
Diodes picked to withstand up to 35V, at a continuous 1A

Power Sense:
Voltage divider can take up to 35Vs sensing range

Sheet Title: RADC POWER (12V & USB, 12V Protection, 3V3 Out)

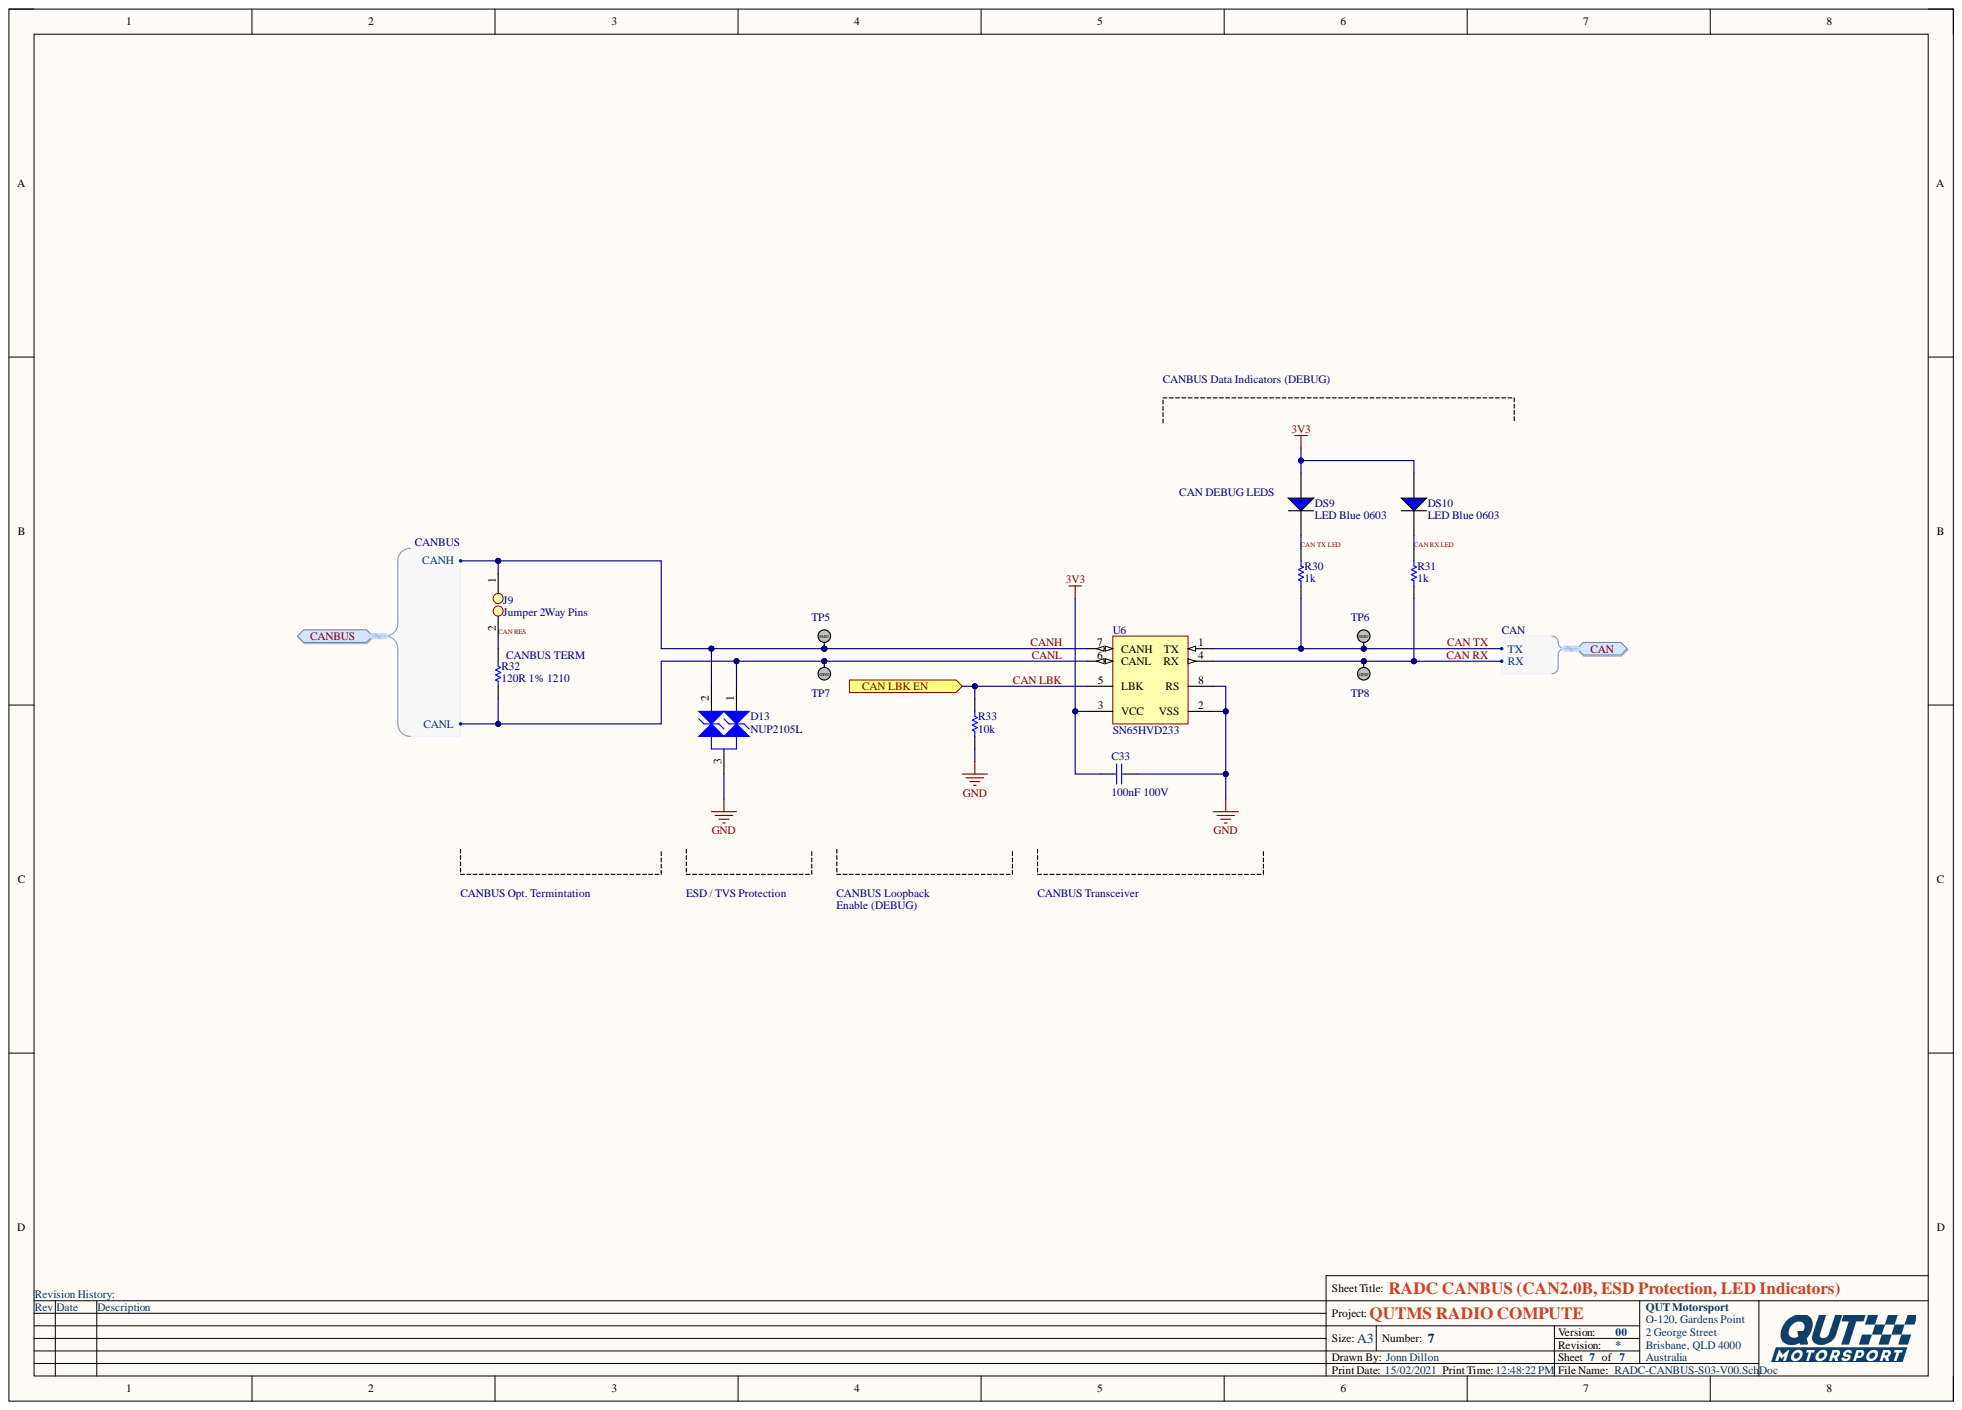
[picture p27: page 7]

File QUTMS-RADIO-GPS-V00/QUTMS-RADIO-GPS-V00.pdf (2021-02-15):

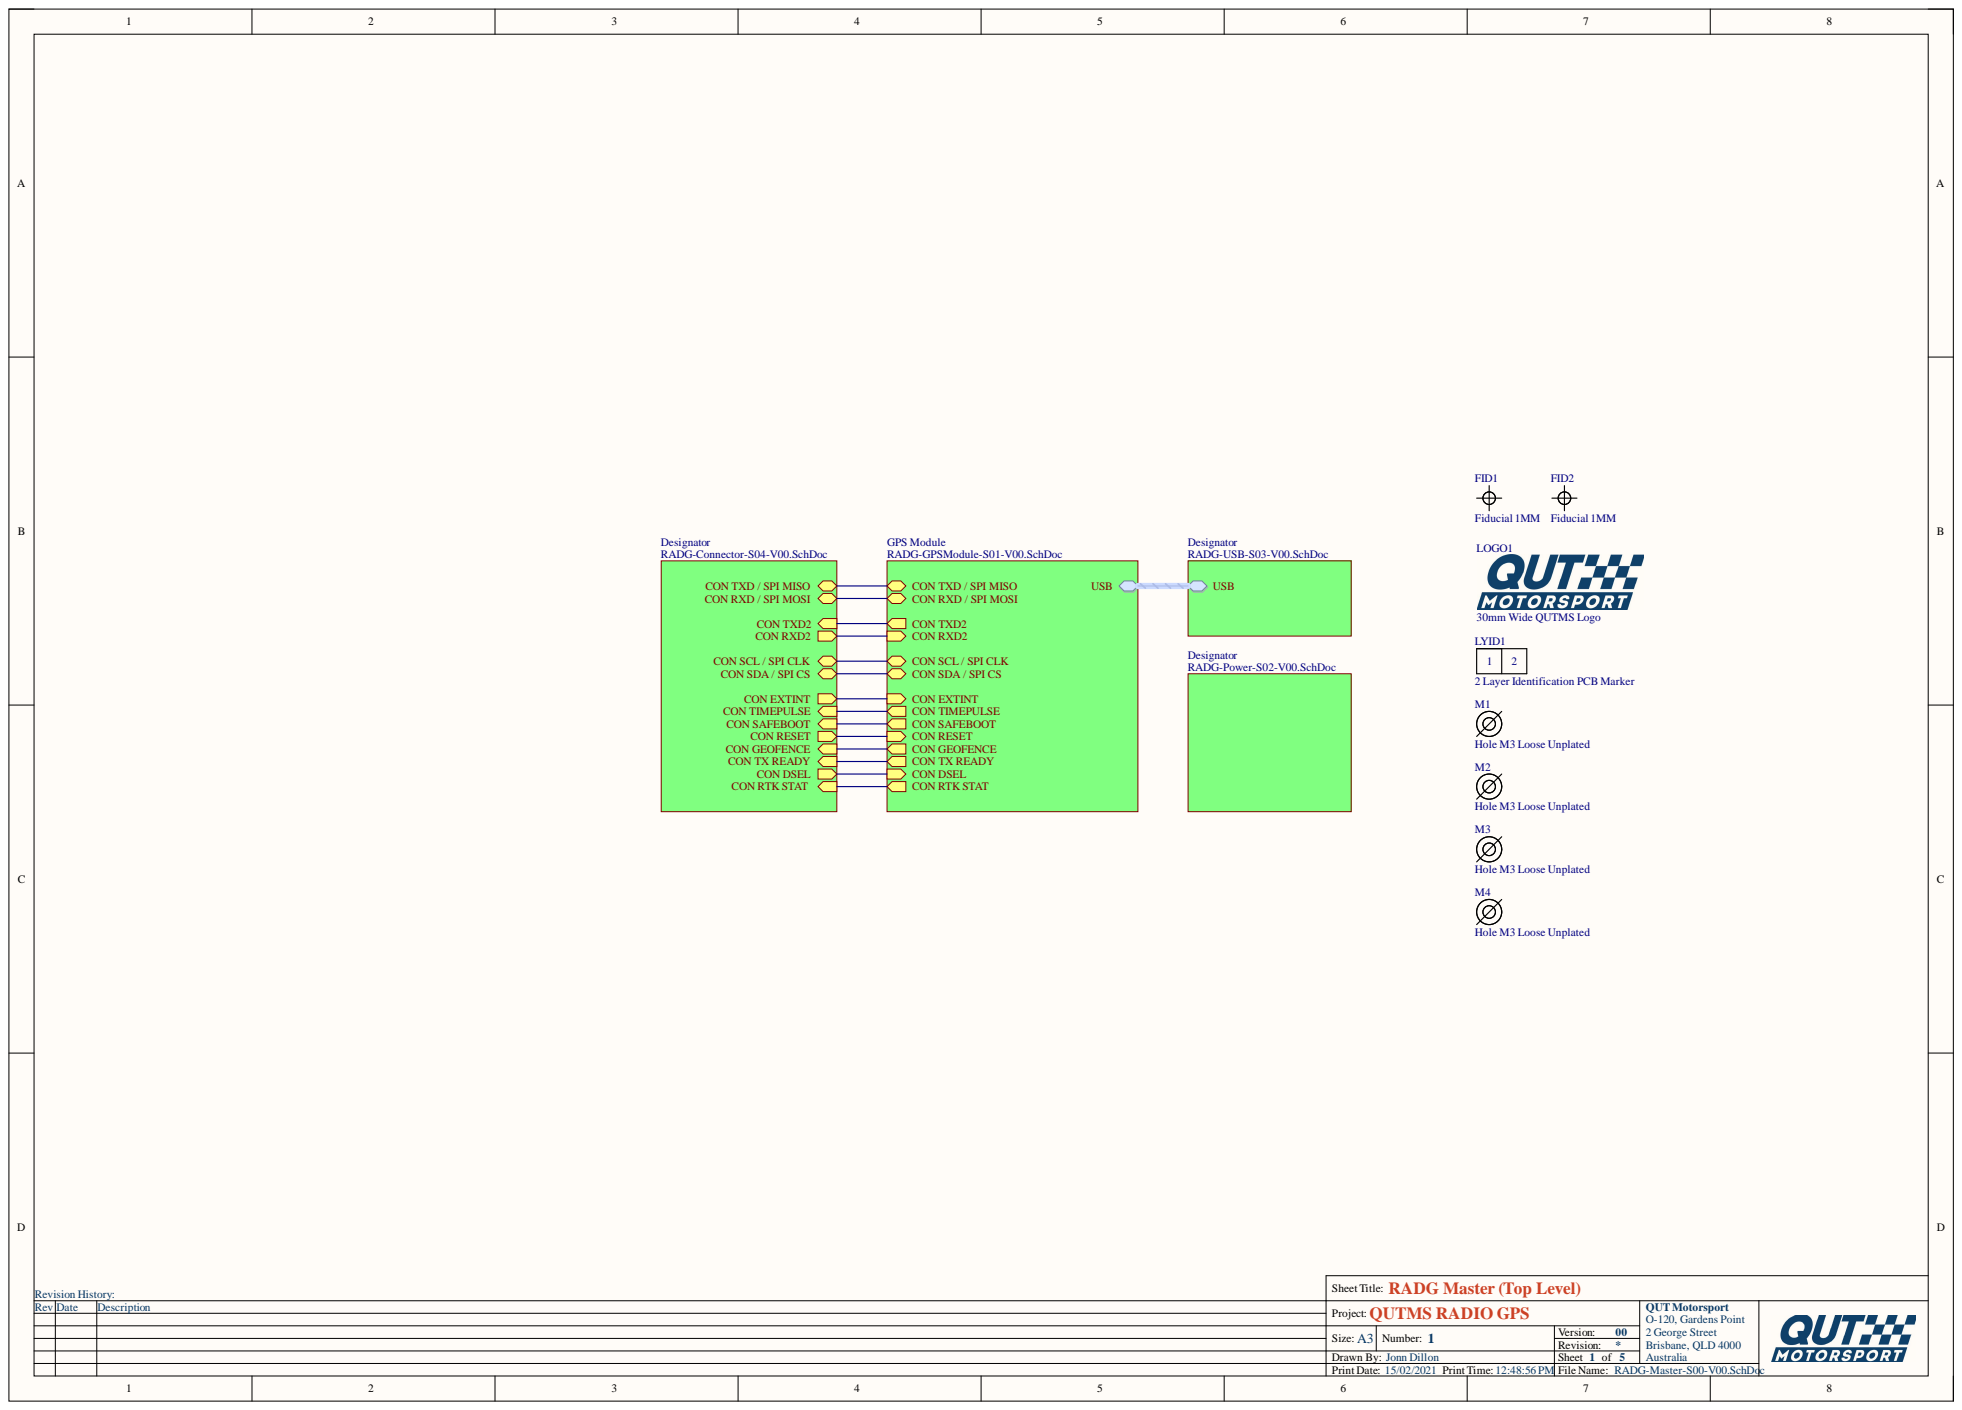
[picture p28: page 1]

CON TXD / SPI MISO
CON RXD / SPI MOSI

CON SCL / SPI CLK
CON SDA / SPI CS

2 Layer Identification PCB Marker

Sheet Title: RADG Master (Top Level)
QUTMS RADIO GPS

Drawn By: Jonn Dillon

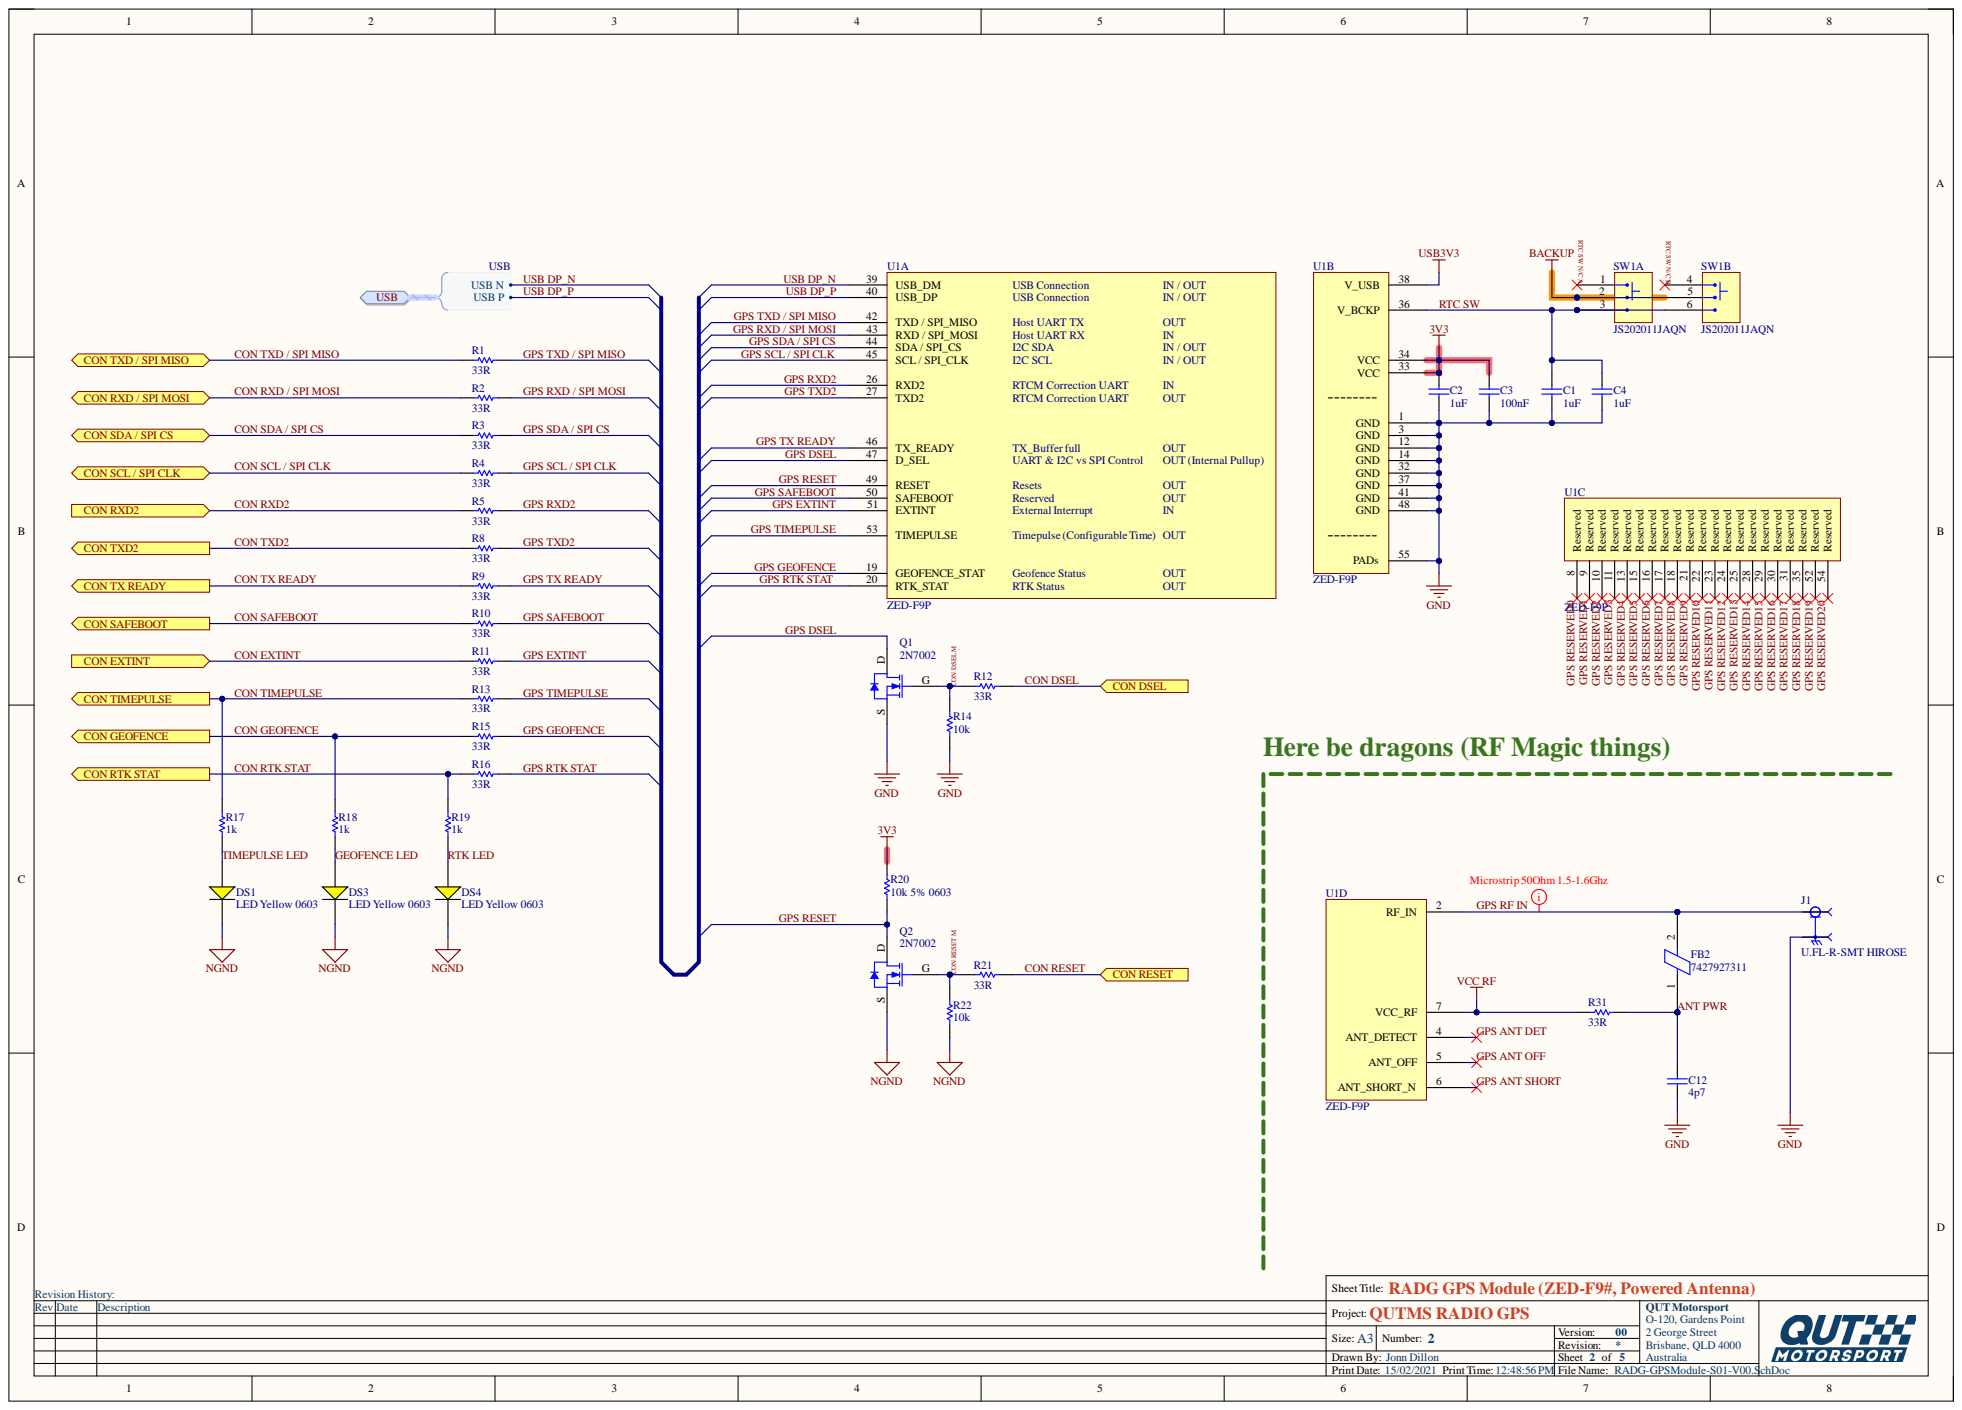
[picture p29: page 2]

USB DP_P USB DP_N GPS SDA / SPI C

RT & I2C vs SPI Cont

CON RESET M CON DSELM

Here be dragons (RF Magic things)

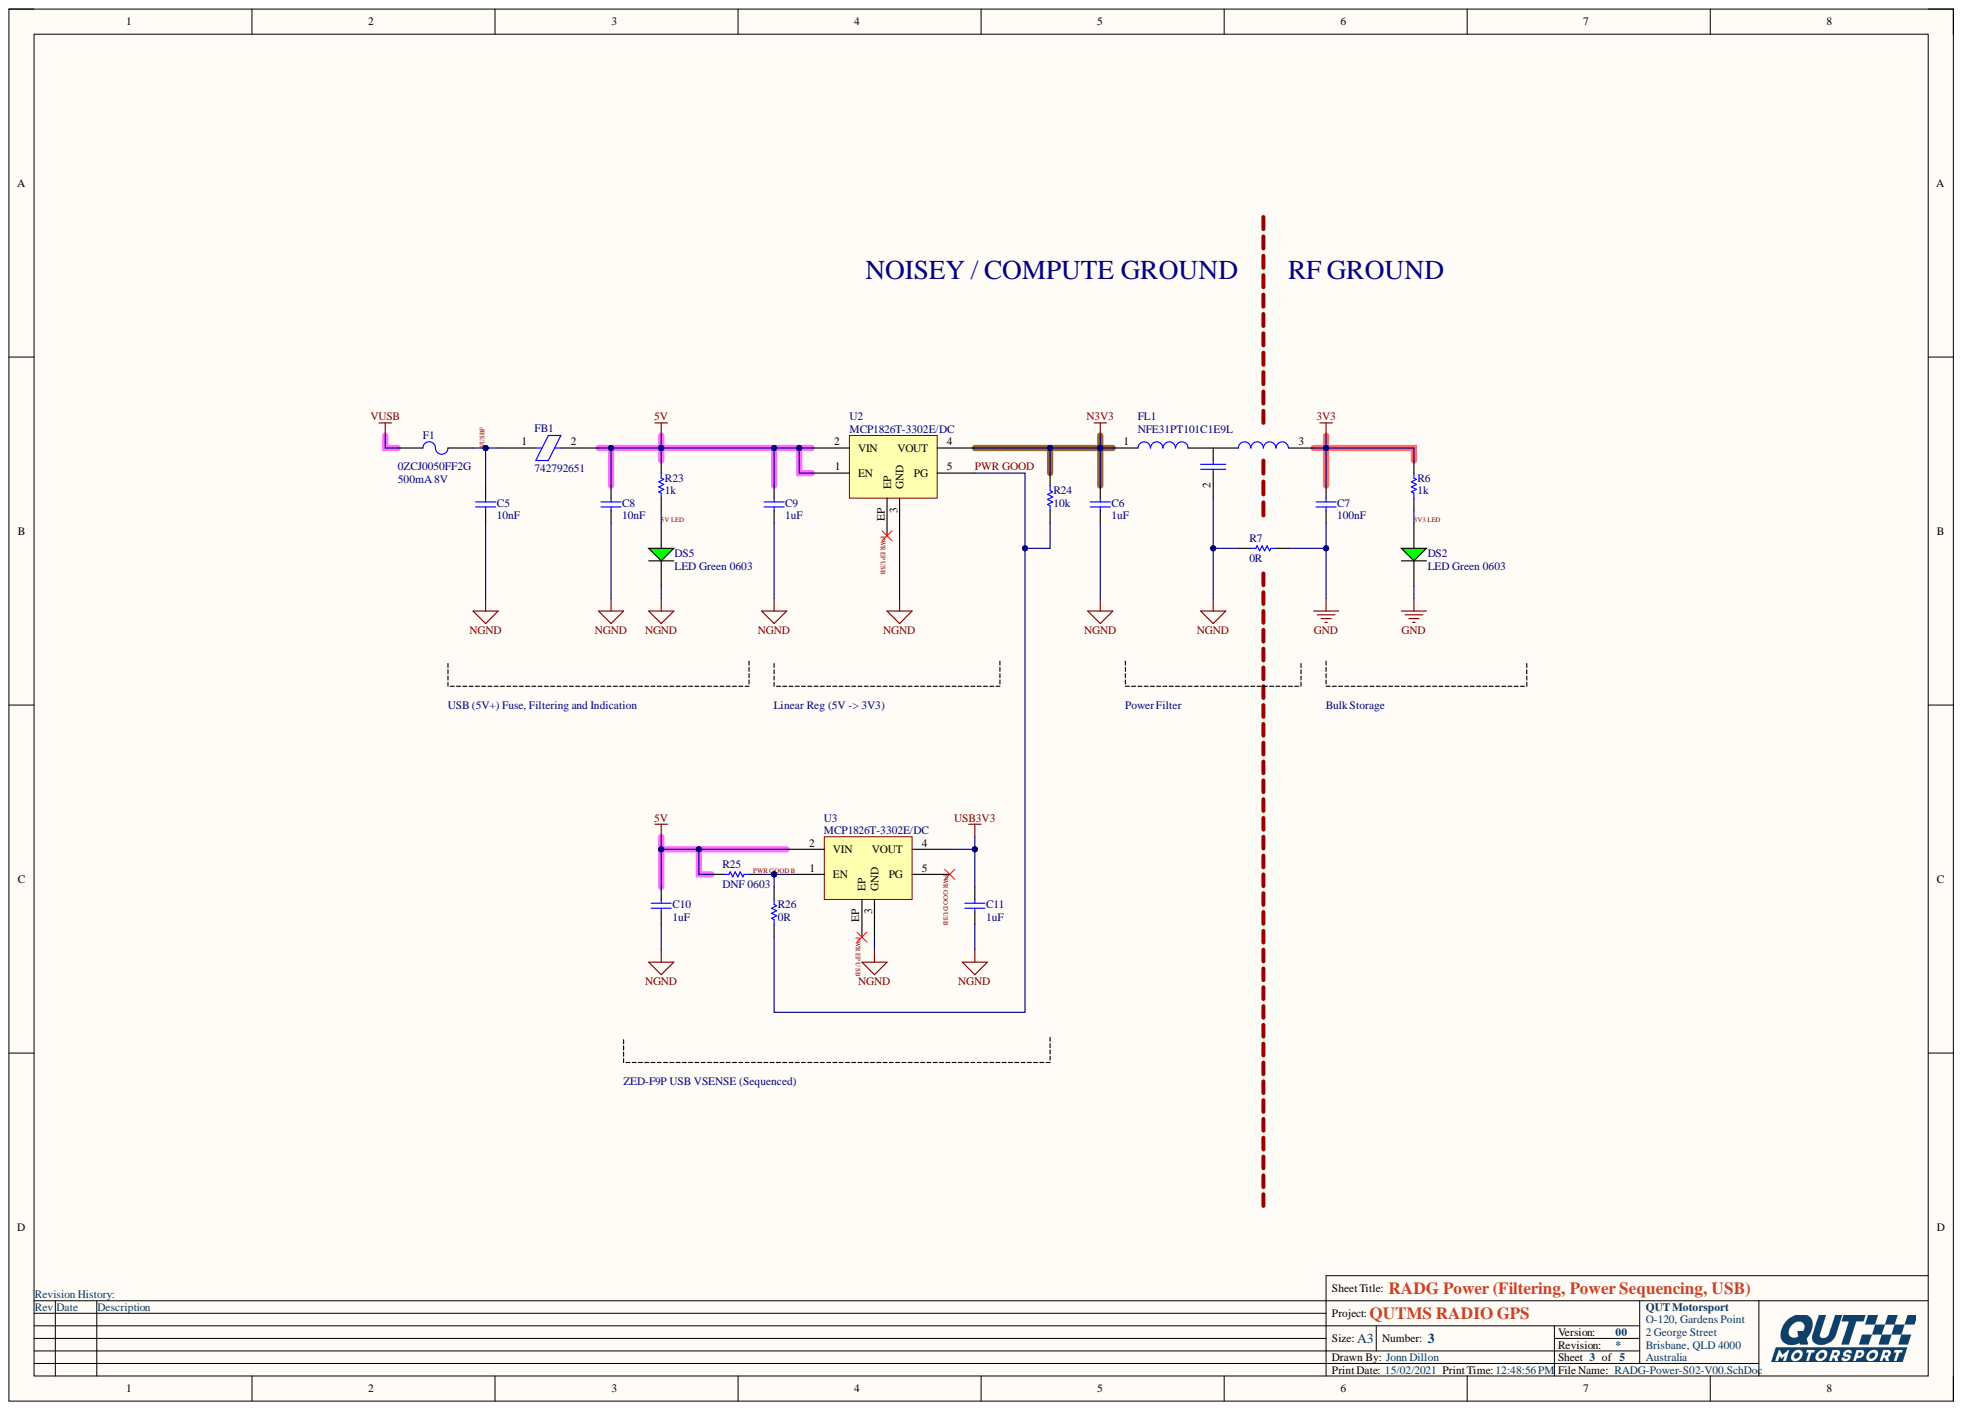
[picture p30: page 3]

ZED-F9P USB VSENSE (Sequenced)

Sheet Title: RADG Power (Filtering, Power Sequencing, USB)

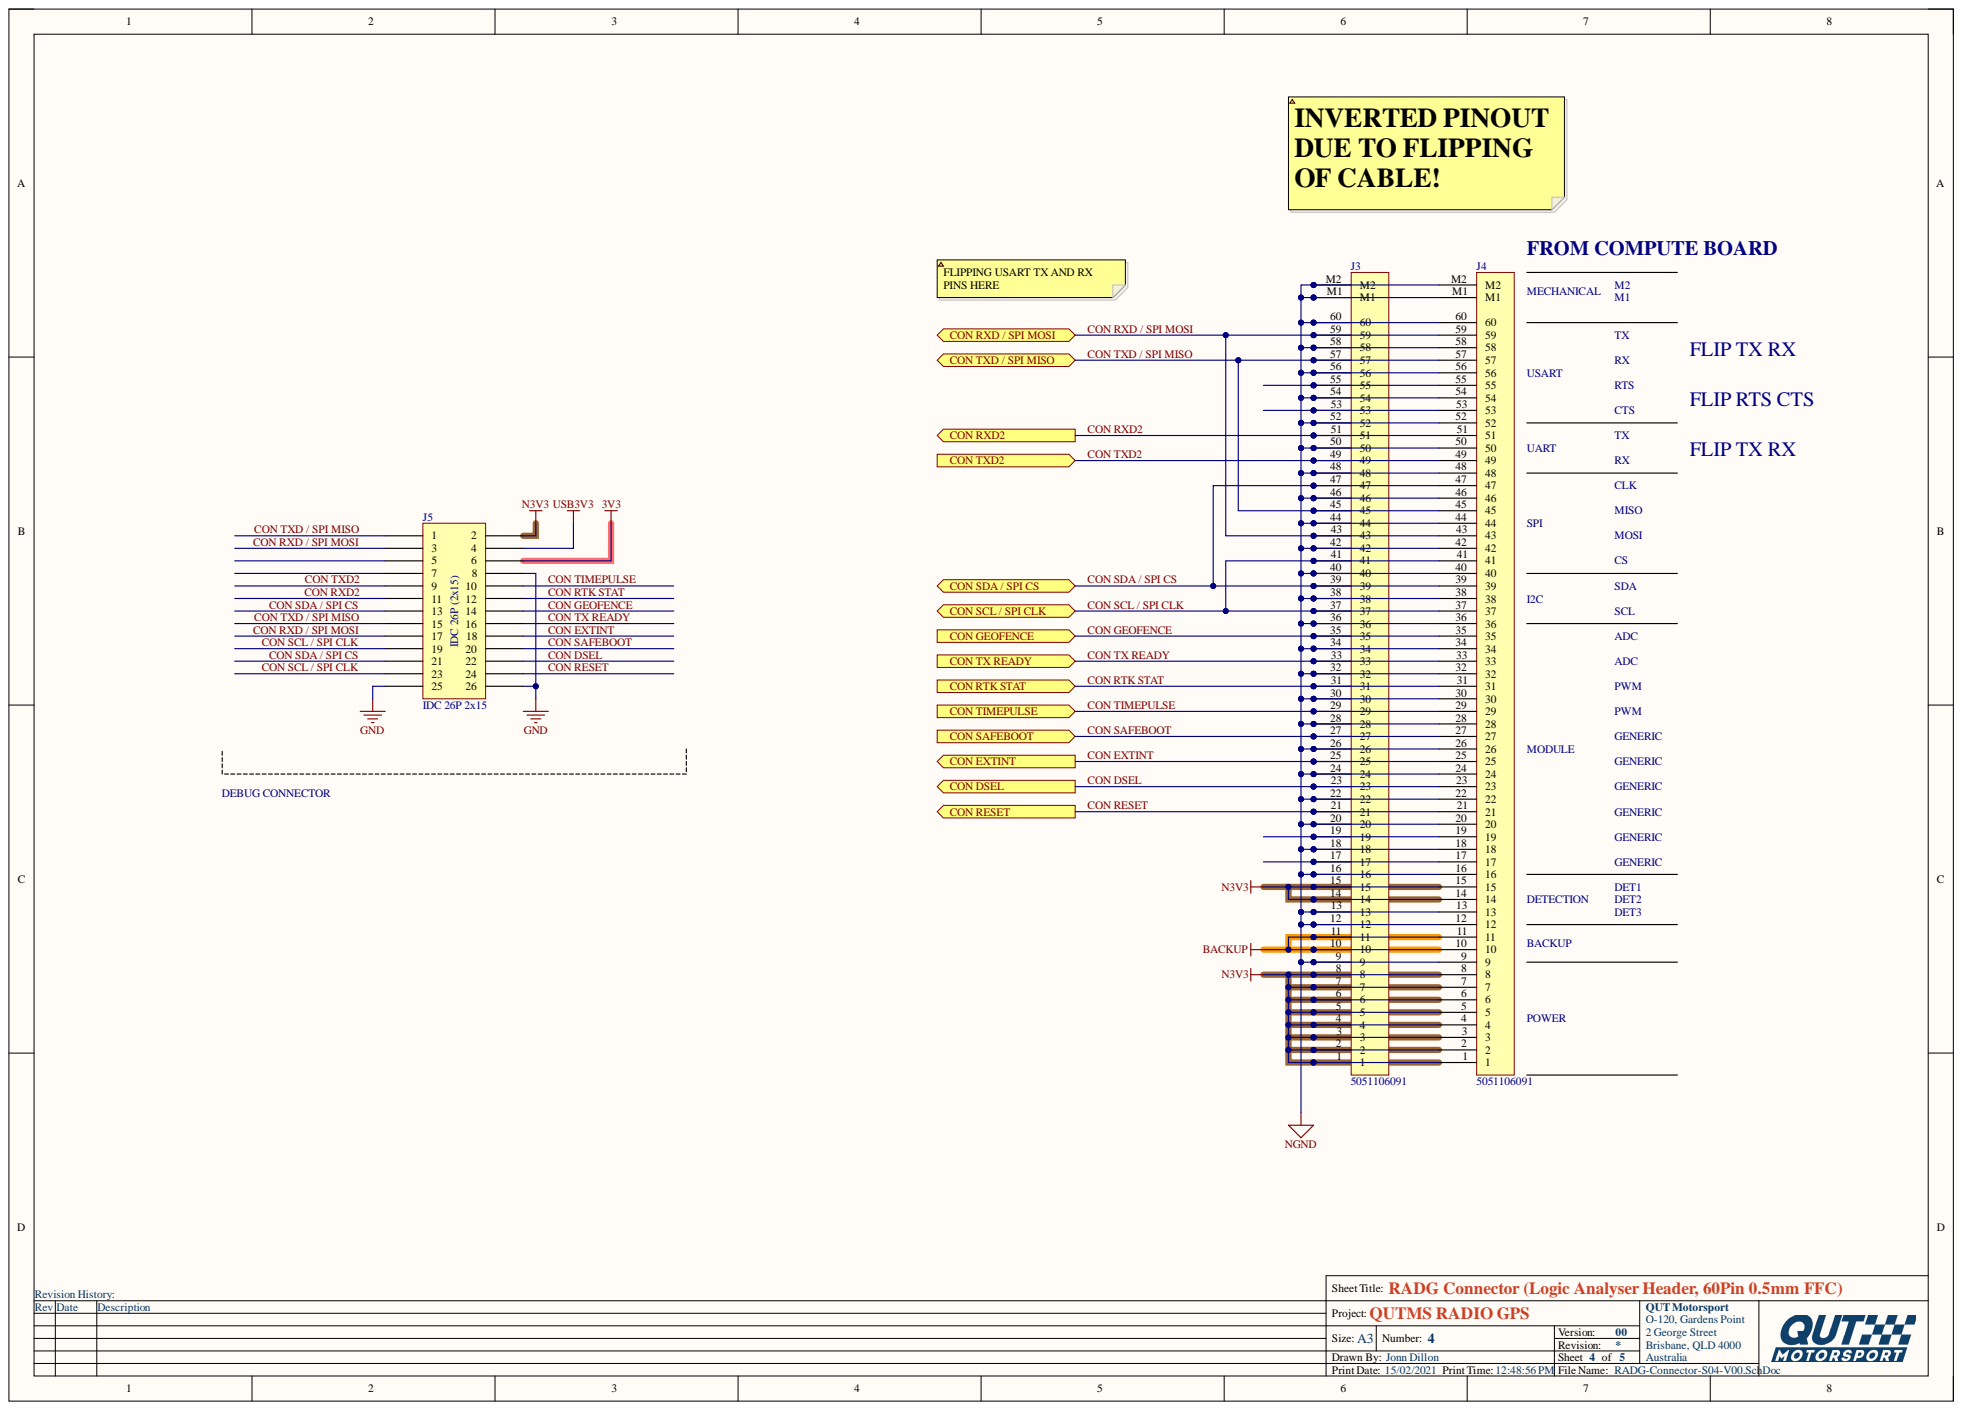
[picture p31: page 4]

FLIPPING USART TX AND RX
PINS HERE

CON SDA / SPI CS | 1 1 2 2 3 3 4 4 5 5 6 6 7 7 8 8 9 9 10 10 11 11 12 12 13 13 14 14 15 15 16 16 17 17 18 18 19 19 20 20 21 21 22 22 23 23 24 24 25 25 26 26 27 27 28 28 29 29 30 30 31 31 32 32 33 33 34 34 35 35 36 36 37 37 38 38 39 39 40 40 41 41 42 42 43 43 44 44 45 45 46 46 47 47 48 48 49 49 50 50 51 51 52 52 53 53 54 54 55 55 56 56 57 57 58 58 59 59 60 60 | 1 1 2 2 3 3 4 4 5 5 6 6 7 7 8 8 9 9 10 10 11 11 12 12 13 13 14 14 15 15 16 16 17 17 18 18 19 19 20 20 21 21 22 22 23 23 24 24 25 25 26 26 27 27 28 28 29 29 30 30 31 31 32 32 33 33 34 34 35 35 36 36 37 37 38 38 39 39 40 40 41 41 42 42 43 43 44 44 45 45 46 46 47 47 48 48 49 49 50 50 51 51 52 52 53 53 54 54 55 55 56 56 57 57 58 58 59 59 60 60

CON RXD / SPI MOSI

CON TXD / SPI MISO

CON RXD2

CON TXD2

CON SDA / SPI CS

CON SCL / SPI CLK

Sheet Title: RADG Connector (Logic Analyser Header, 60Pin 0.5mm FFC)

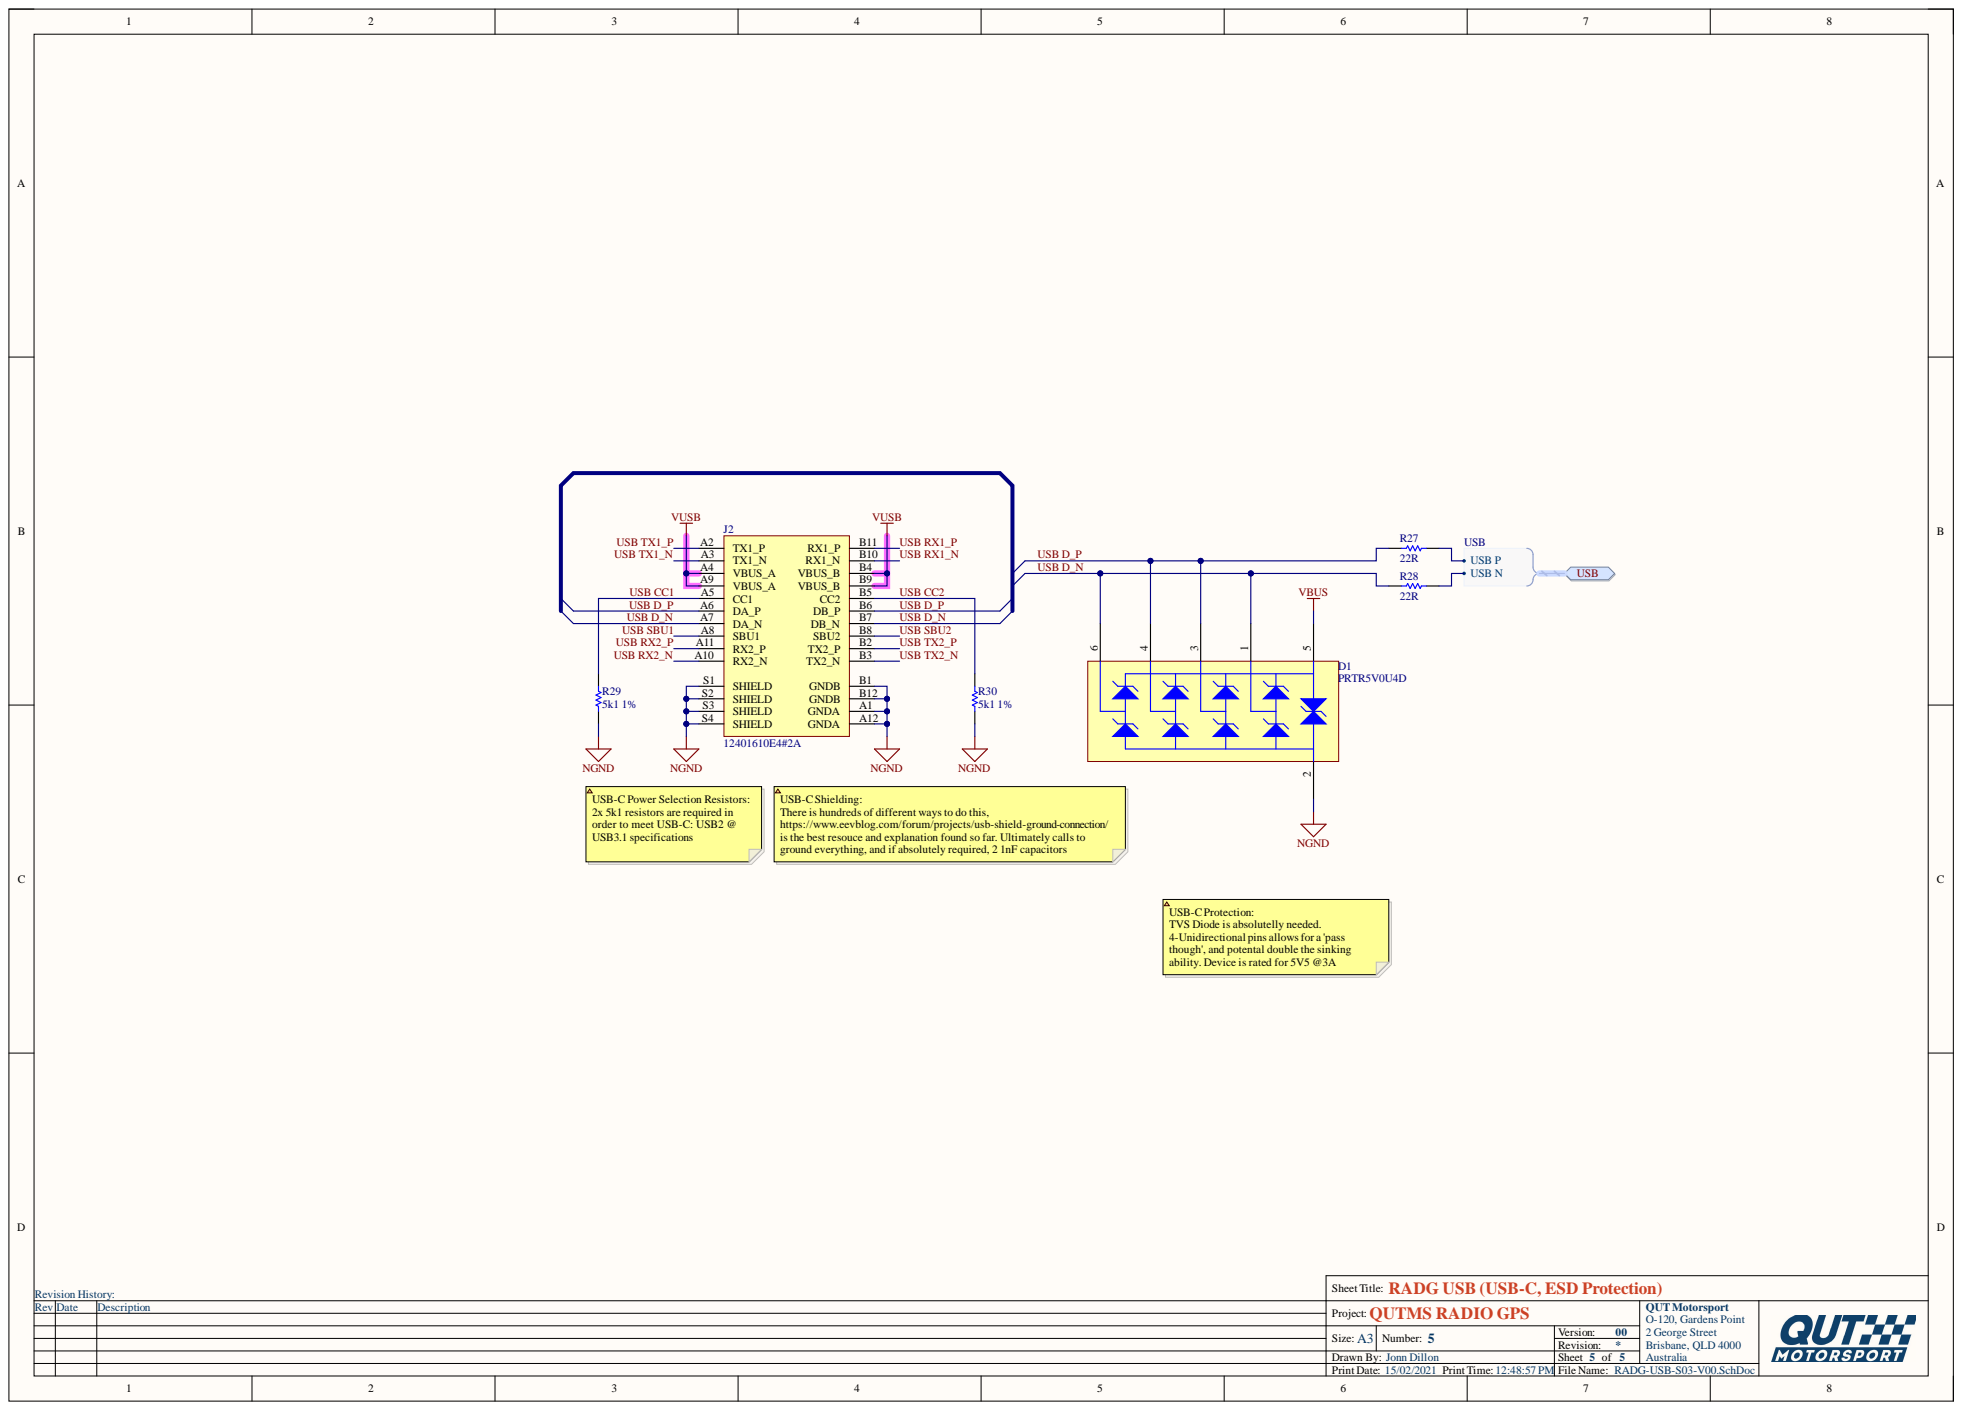
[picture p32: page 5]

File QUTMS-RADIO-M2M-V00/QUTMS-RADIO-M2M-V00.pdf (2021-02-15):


Radio Module (Digi SX Radio 900Mhz)
RADM-RadioModule-S01-V00.SchDoc

2 Layer Identification PCB Marker

Power Supply (Filtering, Regulation)
RADM-Power-S02-V00.SchDoc

Sheet Title: RADM Master (Machine 2 Machine Radio, Top Level)
QUTMS RADIO M2M

Drawn By: Jonn Dillon


Modules Pins can only sink
4mA each!, Max of 40mA!



USB D_P USB D_N USB SB U 1 USB R X2_P USB R X2_N | A | B 1 | USB D_P USB D_N USB SB U 2 USB T X2_P USB T X2_N

USB T X L E D

U SB CBU


RSSI 70 LED RSSI 60 LED RSSI 45 LED RSSI 80 LED

RSSI 70 RSSI 60 RSSI 45 RSSI 80

RSSI 70 R

RSSI 60 R

RSSI 45 R

Realisticly will probebrly never be lit
Only in extreme noise, or too close

'Perfect Value'
Resistor Network closely approximates

RSSI Signal:
PWM @ 120Hz, Duty cycle percent directly
proportial to -dB. IE: 10% duty cycle = 10 dB fade
margin (signal level of -100 dBm @ 9600 bps, -94
dBm @ 115 bps).

Digi "What is RSSI"
https://www.digi.com/support/knowledge-base/data-integrity-and-received-signal-strength

Digi Radios PWM RSSI Pin Specification
https://www.digi.com/support/knowledge-base/pwm-rssi-signal-atrp-command-for-analog-rssi-indic

Sheet Title: RADM Supporting Circuity (RSSI Indicator)


FLIPPING USART TX AND RX
PINS HERE

Sheet Title: RADM Connector (Logic Analyser Header, 60Pin 0.5mm FFC)


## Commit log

2021-01-27 Inital Part Selection (Radio and GPS)
    [RadioPartsComparison.xlsx]
2021-01-27 Started projects for each pcb. Added in personal updated libraries. Made parts for Digi SX and uBlox ZED-F9
    [Digi_XbeeSX.PcbLib, Digi_XbeeSX.SchLib, QUTMS-RADIO-COMPUTE-V00.PrjPcb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]
2021-01-28 Finalised radio parts, and added SchDOTs for motorsport
    [Digi_XbeeSX.PcbLib, Digi_XbeeSX.SchLib, RADM-Master-S00-V00.SchDoc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]
2021-01-28 Everything from today
    [PCIE-036-02-F-D-RA.stp, QUTMS-RADIO-COMPUTE-V00.PrjPcb, QUTMS-RADIO-GPS-V00.PrjPcb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]
2021-01-29 Finalised compute modules power stage, added DC barrel jack, added SD card, updated Master for compute, added lots of libraries and parts. Made a linked TLA for the whole project
    [0ZCJ0005FF2E.step, CUI_PJ-102A.STEP, QUTMS-RADIO-COMPUTE-V00.PrjPcb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]
2021-02-01 Finalised USB solution
    [61300411121_Download_STP_61300411121_rev1.stp, QUTMS-RADIO-USB-V00.PrjPcb, QUTMS_DiodeLibrary.PcbLib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]
2021-02-01 Finalised USB issues, finalised selection of board stackup / module connector
    [QUTMS-RADIO-USB-V00.PrjPcb, QUTMS_CANLibrary.PcbLib, QUTMS_CANLibrary.SchLib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]
2021-02-01 Some files forgotten
    [RADC-Peripherals-S05-V00.SchDoc, RADC-Power-S04-V00.SchDoc]
2021-02-02 Started major work on module cards, desgined power filtering stage, added secondary canbus for future use, selected microcontroller
    [CardConnectorSpecification-V1.xlsx, NFE31PT101C1E9L.STEP, QUTMS-RADIO-COMPUTE-V00.PrjPcb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]
2021-02-03 Majority of M2M module complete, prelim items for GPS module complete, added RTC batteries, figured out RSSI charatices for SX radio (not present in datasheet)
    [Digi_SXRadio_RSSIFinalSelection.xlsx, Digi_SXRadio_RSSIPinCorrelation.xlsx, JS202011JCQN.stp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]
2021-02-03 Added RTCBattery Calculations from laptop
    [RTCBatteryCalculations.xlsx]
2021-02-04 Added supercamp backup, changed usb connection method, added power sequencing to gps, named everything, altered protections / driving for M2M and GPS to be simplified
    [Aluminum_electrolytic_capacitor_radial_D6.3_H9_PinD0.5_Pitch2.5_nominal_orange.step, Digi_XbeeSX.PcbLib, JST - PH - SMD (R) - 4Pin - 2.00mm.stp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]
2021-02-04 Missed some files
    [QUTMS-RADIO-GPS-V00.PrjPcb, QUTMS-RADIO-M2M-V00.PrjPcb, RADG-Master-S00-V00.SchDoc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]
2021-02-05 Added micro (STM32F446V#), started wiring it up to the main compute board
    [LQFP100_14X14X1.6_P0.5_ST.step, QUTMS-RADIO-COMPUTE-V00.PrjPcb, QUTMS_STM32Library.PcbLib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]
2021-02-08 Reworking system to use flat flex vs edge connectors (lots of work)
    [20-Pin Shrouded Header (IDC) Straight.stp, 30326-6002.stp, 68021-x08.igs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]
2021-02-08 Defined lots of outlines and nailed down mechanical implimentation
    [QUTMS-RADIO-COMPUTE-V00.PrjPcb, QUTMS-RADIO-GPS-V00.PrjPcb, QUTMS-RADIO-M2M-V00.PrjPcb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]
2021-02-09 Deleted History folders. Made a master board doc, added mechanical fixtures and parts. Finalised mechanical layouts and dimentions. Prelim placement of parts for compute board. Started on a new case.
    [M3x1.8mm Hex Nut.step, M3x8.STEP, QUTMS-RADIO-CASE-V00.SLDPRT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]
2021-02-11 Modified Diode library
    [QUTMS_DiodeLibrary.PcbLib, QUTMS_DiodeLibrary.SchLib]
2021-02-11 Moving to 144 pin MCU
    [QUTMS-RADIO-COMPUTE-V00.PrjPcb, QUTMS_DiodeLibrary.PcbLib, QUTMS_DiodeLibrary.SchLib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]
2021-02-11 Retooled mcu sheet, part, pins etc to use 144 pin varient. Laid out power supply and power planes of COMPUTE board
    [CaseParameters.xlsx, QUTMS-RADIO-COMPUTE-V00.PrjPcb, QUTMS_RadioLibrary.SchLib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]
2021-02-12 Finished part selection, pinning and placement for compute module
    [022288030.stp, 022288040.stp, QUTMS-RADIO-COMPUTE-V00.PrjPcb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]
2021-02-12 Added pin allocations document
    [MCUPinAllocations.xlsx]
2021-02-15 Commit for big review A
    [74279270_Download_STP_WE-CBF-0402_rev1.stp, JS202011JAQN.stp, MCUPinAllocations.xlsx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]
2021-02-15 Finalised review, all final schematic changes have been made. Routing is all that is left
    [1812_RES.stp, QUTMS-RADIO-COMPUTE-V00.PrjPcb, QUTMS-RADIO-GPS-V00.PrjPcb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]
2021-02-16 Effectivly finished first pass of compute board. Still to check potential cross talk, label everything, and route inidication wires
    [QUTMS-RADIO-COMPUTE-V00.PrjPcb, QUTMS-RADIO-GPS-V00.PrjPcb, QUTMS-RADIO-M2M-V00.PrjPcb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]
2021-02-17 Finalised compute board
    [QUTMS-RADIO-COMPUTE-V00.PrjPcb, QUTMS_PCBLibrary.PcbLib, QUTMS_PCBLibrary.SchLib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]
2021-02-18 Added lots of content along with actual presentation
    [OLEDDisplay1-3inch.stp, QUTMS-RADIO-COMPUTE-V00.PrjPcb, RADC-Power-S05-V00.SchDoc]
2021-02-18 Changed a few items while laying out the GPS module a bit more
    [QUTMS_RadioLibrary.PcbLib, RADC-Master-S00-V00.SchDoc, RADC-Power-S05-V00.SchDoc]
2021-02-24 Reworking whole system to be seperate boards for M2M and GNSS, to be inline with better RF practices
    [OLED_0.91_128x32.stp, QUTMS-RADIO-COMPUTE-V00.PrjPcb, QUTMS-RADIO-GPS-V00.PrjPcb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]
2021-03-08 Finished V1 of Radio Pod... Gerber export located in RAD-COMPILE directroy
    [022288030.stp, 022288040.stp, 0ZCJ0005FF2E.step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]
2021-03-09 Minor pcb updates, updated README with PCB ordering instructions
    [QUTMS-RAD-COMPILE-V00.PrjPcb, QUTMS-RADIO-COMPUTE-V00.PrjPcb, RAD-B00-V00.PcbDoc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]

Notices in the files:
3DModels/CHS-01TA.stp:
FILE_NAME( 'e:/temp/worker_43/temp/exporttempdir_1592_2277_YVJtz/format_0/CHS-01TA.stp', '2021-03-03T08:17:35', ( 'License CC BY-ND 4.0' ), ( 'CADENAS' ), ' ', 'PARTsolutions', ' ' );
